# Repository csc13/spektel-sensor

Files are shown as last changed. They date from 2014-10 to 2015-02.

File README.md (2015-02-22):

spektel-sensor
==============
*[See the project blog here!](http://spektel.cescholz.de/)* 

This is a small project for a XMEGA based sensor for the Spektrum-RC telemetry system.
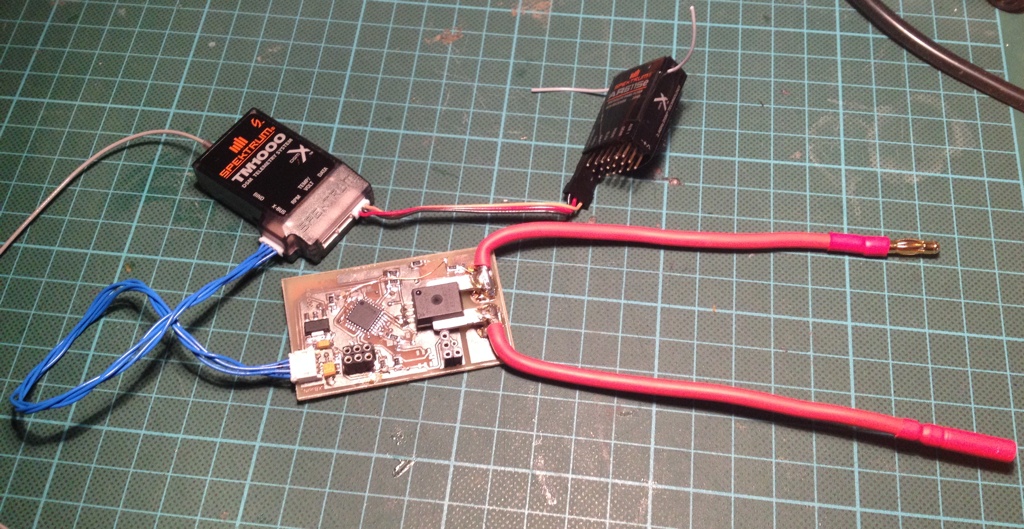
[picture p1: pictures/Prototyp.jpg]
spektrum Sensor Prototype


The sensor is based on the flowing components:
- Atmel XMEGA32E5
- Allegro ACS758LCB-100U hall effect current sensor
- Bosch BMP180 pressure sensor (planned)

The firmware was developed in C using Atmel Studio 6 and the Atmel ASF framework.

	Note: The Spektrum RC TM1000 telemetry modul, a DSMX receiver with data port and a 
	transmitter with telemetry functions are required to use the sensor. Not all Spektrum RC telemetry able
	transmitters support all sensors. I use a DX9 for testing.

### Basic functions
The sensor measures 25 times a second the actual current, voltage and pressure. From this 
it calculates the used capacity, hight and climb rate.

- Show used capacity of main battery
- Show actual current of main battery
- Show actual voltage of main battery
- Show altitude
- Programmable via on button (change the battery capacity)

### Planned functions
- Show climb rate
- Show cell voltages of main battery

### Project Structure
- firmware (compiled firmware for XMEGA)
- flight_logs (from Spektrum transmitter)
- hardware (Eagle PCB files)
- pictures (photos)
- project (Atmel Studio, make files, etc.)
- src (C sources)

### History
#### 2014-10-28: Initial upload with REV_A board layout
- Please note that REV_A is the initial prototype and has several bugs

#### 2014-11-02: Added support for RealtimePlotter and arduplot
Two two great serial monitors based on Processing (https://www.processing.org/).
Please see https://github.com/sebnil/RealtimePlotter.git and see https://github.com/dahart/arduplot.git).

#### 2015-01-19: Added support for the REV_B board
This includes the smaller board, BMP180 altitude measurement, setup button, self calibration.

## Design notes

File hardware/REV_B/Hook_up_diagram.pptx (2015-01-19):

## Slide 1

Spektrum TM1000

Optional GND connection, if not via receiver BEC from ESC

Main Battery pack

X-Bus

Spektel Sensor REV_B
(bottom side)

+

Electronic Speed Controller

spektel.cescholz.de

+

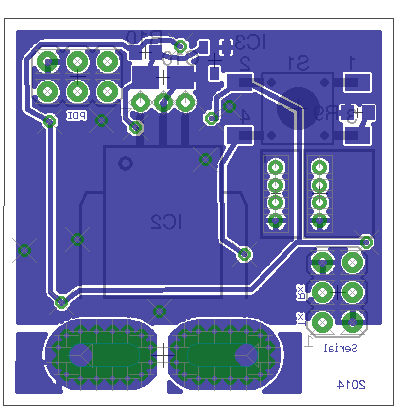
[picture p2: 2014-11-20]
hardware/REV_B/Bottom_Layer_REV_B.png

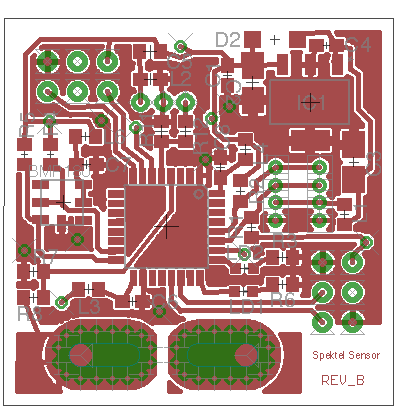
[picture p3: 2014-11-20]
hardware/REV_B/Top_Layer_REV_B.png

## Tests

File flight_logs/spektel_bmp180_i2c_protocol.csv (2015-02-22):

Time [s] | Analyzer Name | Decoded Protocol Result
0.000012825000000 | I2C | Setup Write to ['238' (0xEE)] + ACK
0.000053850000000 | I2C | '208' (0xD0) + ACK
0.000122950000000 | I2C | Setup Read to ['239' (0xEF)] + ACK
0.000161250000000 | I2C | U (0x55) + NAK
0.000234550000000 | I2C | Setup Write to ['238' (0xEE)] + ACK
0.000275575000000 | I2C | '244' (0xF4) + ACK
0.000317450000000 | I2C | '192' (0xC0) + ACK
0.000390350000000 | I2C | Setup Write to ['238' (0xEE)] + ACK
0.000431350000000 | I2C | '244' (0xF4) + ACK
0.000500450000000 | I2C | Setup Read to ['239' (0xEF)] + ACK
0.000538750000000 | I2C | '192' (0xC0) + NAK
0.000612050000000 | I2C | Setup Write to ['238' (0xEE)] + ACK
0.000653100000000 | I2C | '170' (0xAA) + ACK
0.000722225000000 | I2C | Setup Read to ['239' (0xEF)] + ACK
0.000760525000000 | I2C | ' ' (0x20) + ACK
0.000802175000000 | I2C | '212' (0xD4) + NAK
0.000875475000000 | I2C | Setup Write to ['238' (0xEE)] + ACK
0.000916525000000 | I2C | '172' (0xAC) + ACK
0.000985650000000 | I2C | Setup Read to ['239' (0xEF)] + ACK
0.001023950000000 | I2C | '251' (0xFB) + ACK
0.001065625000000 | I2C | r (0x72) + NAK
0.001139000000000 | I2C | Setup Write to ['238' (0xEE)] + ACK
0.001180025000000 | I2C | '174' (0xAE) + ACK
0.001249150000000 | I2C | Setup Read to ['239' (0xEF)] + ACK
0.001287425000000 | I2C | '199' (0xC7) + ACK
0.001329100000000 | I2C | # (0x23) + NAK
0.001402425000000 | I2C | Setup Write to ['238' (0xEE)] + ACK
0.001443450000000 | I2C | '176' (0xB0) + ACK
0.001512525000000 | I2C | Setup Read to ['239' (0xEF)] + ACK
0.001550825000000 | I2C | '128' (0x80) + ACK
0.001592500000000 | I2C | '234' (0xEA) + NAK
0.001665850000000 | I2C | Setup Write to ['238' (0xEE)] + ACK
0.001706875000000 | I2C | '178' (0xB2) + ACK
0.001776025000000 | I2C | Setup Read to ['239' (0xEF)] + ACK
0.001814325000000 | I2C | b (0x62) + ACK
0.001855950000000 | I2C | '203' (0xCB) + NAK
0.001929300000000 | I2C | Setup Write to ['238' (0xEE)] + ACK
0.001970325000000 | I2C | '180' (0xB4) + ACK
0.002039425000000 | I2C | Setup Read to ['239' (0xEF)] + ACK
0.002077725000000 | I2C | E (0x45) + ACK
0.002119400000000 | I2C | 1 (0x31) + NAK
0.002192750000000 | I2C | Setup Write to ['238' (0xEE)] + ACK
0.002233800000000 | I2C | '182' (0xB6) + ACK
0.002302925000000 | I2C | Setup Read to ['239' (0xEF)] + ACK
0.002341225000000 | I2C | '25' (0x19) + ACK
0.002382900000000 | I2C | s (0x73) + NAK
0.002456275000000 | I2C | Setup Write to ['238' (0xEE)] + ACK
0.002497275000000 | I2C | '184' (0xB8) + ACK
0.002566375000000 | I2C | Setup Read to ['239' (0xEF)] + ACK
0.002604700000000 | I2C | '0' (0x00) + ACK
0.002646375000000 | I2C | - (0x2D) + NAK
0.002719750000000 | I2C | Setup Write to ['238' (0xEE)] + ACK
0.002760775000000 | I2C | '186' (0xBA) + ACK
0.002829900000000 | I2C | Setup Read to ['239' (0xEF)] + ACK
0.002868200000000 | I2C | '128' (0x80) + ACK
0.002909875000000 | I2C | '0' (0x00) + NAK
0.002983250000000 | I2C | Setup Write to ['238' (0xEE)] + ACK
0.003024275000000 | I2C | '188' (0xBC) + ACK
0.003093375000000 | I2C | Setup Read to ['239' (0xEF)] + ACK
0.003131700000000 | I2C | '209' (0xD1) + ACK
0.003173375000000 | I2C | '246' (0xF6) + NAK
0.003246750000000 | I2C | Setup Write to ['238' (0xEE)] + ACK
0.003287775000000 | I2C | '190' (0xBE) + ACK
0.003356900000000 | I2C | Setup Read to ['239' (0xEF)] + ACK
0.003395225000000 | I2C | \n (0x0A) + ACK
0.003436900000000 | I2C | S (0x53) + NAK
0.003510275000000 | I2C | Setup Write to ['238' (0xEE)] + ACK
0.003551350000000 | I2C | '244' (0xF4) + ACK
0.003593250000000 | I2C | . (0x2E) + ACK
0.008666775000000 | I2C | Setup Write to ['238' (0xEE)] + ACK
0.008707800000000 | I2C | '246' (0xF6) + ACK
0.008776900000000 | I2C | Setup Read to ['239' (0xEF)] + ACK
0.008815200000000 | I2C | c (0x63) + ACK
0.008856850000000 | I2C | '225' (0xE1) + NAK
0.009004475000000 | I2C | Setup Write to ['238' (0xEE)] + ACK
0.009045475000000 | I2C | '244' (0xF4) + ACK
0.009087375000000 | I2C | '244' (0xF4) + ACK
0.020256700000000 | I2C | Setup Write to ['238' (0xEE)] + ACK
0.020297725000000 | I2C | '246' (0xF6) + ACK
0.020366875000000 | I2C | Setup Read to ['239' (0xEF)] + ACK
0.020405200000000 | I2C | c (0x63) + ACK
0.020446850000000 | I2C | '225' (0xE1) + NAK
0.020520200000000 | I2C | Setup Write to ['238' (0xEE)] + ACK
0.020561250000000 | I2C | '248' (0xF8) + ACK
0.020630375000000 | I2C | Setup Read to ['239' (0xEF)] + ACK
0.020668675000000 | I2C | '0' (0x00) + NAK
0.021004075000000 | I2C | Setup Write to ['238' (0xEE)] + ACK
0.021045150000000 | I2C | '244' (0xF4) + ACK
0.021087050000000 | I2C | '244' (0xF4) + ACK
0.060308250000000 | I2C | Setup Write to ['238' (0xEE)] + ACK
0.060349275000000 | I2C | '246' (0xF6) + ACK
0.060418350000000 | I2C | Setup Read to ['239' (0xEF)] + ACK
0.060456625000000 | I2C | '162' (0xA2) + ACK
0.060498275000000 | I2C | '216' (0xD8) + NAK
0.060571625000000 | I2C | Setup Write to ['238' (0xEE)] + ACK
0.060612625000000 | I2C | '248' (0xF8) + ACK
0.060681725000000 | I2C | Setup Read to ['239' (0xEF)] + ACK
0.060720025000000 | I2C | '128' (0x80) + NAK
0.061027975000000 | I2C | Setup Write to ['238' (0xEE)] + ACK
0.061069050000000 | I2C | '244' (0xF4) + ACK
0.061110950000000 | I2C | '244' (0xF4) + ACK
0.100361000000000 | I2C | Setup Write to ['238' (0xEE)] + ACK
0.100402000000000 | I2C | '246' (0xF6) + ACK
0.100471125000000 | I2C | Setup Read to ['239' (0xEF)] + ACK
0.100509425000000 | I2C | '162' (0xA2) + ACK
0.100551100000000 | I2C | '215' (0xD7) + NAK
0.100624400000000 | I2C | Setup Write to ['238' (0xEE)] + ACK
0.100665400000000 | I2C | '248' (0xF8) + ACK
0.100734500000000 | I2C | Setup Read to ['239' (0xEF)] + ACK
0.100772775000000 | I2C | @ (0x40) + NAK
0.101084575000000 | I2C | Setup Write to ['238' (0xEE)] + ACK
0.101125625000000 | I2C | '244' (0xF4) + ACK
0.101167450000000 | I2C | '244' (0xF4) + ACK
0.140422050000000 | I2C | Setup Write to ['238' (0xEE)] + ACK
0.140463075000000 | I2C | '246' (0xF6) + ACK
0.140532225000000 | I2C | Setup Read to ['239' (0xEF)] + ACK
0.140570525000000 | I2C | '162' (0xA2) + ACK
0.140612225000000 | I2C | '216' (0xD8) + NAK
0.140685600000000 | I2C | Setup Write to ['238' (0xEE)] + ACK
0.140726650000000 | I2C | '248' (0xF8) + ACK
0.140795825000000 | I2C | Setup Read to ['239' (0xEF)] + ACK
0.140834125000000 | I2C | ` (0x60) + NAK
0.141142250000000 | I2C | Setup Write to ['238' (0xEE)] + ACK
0.141183300000000 | I2C | '244' (0xF4) + ACK
0.141225200000000 | I2C | '244' (0xF4) + ACK
0.180482600000000 | I2C | Setup Write to ['238' (0xEE)] + ACK
0.180523650000000 | I2C | '246' (0xF6) + ACK
0.180592800000000 | I2C | Setup Read to ['239' (0xEF)] + ACK
0.180631100000000 | I2C | '162' (0xA2) + ACK
0.180672800000000 | I2C | '215' (0xD7) + NAK
0.180746200000000 | I2C | Setup Write to ['238' (0xEE)] + ACK
0.180787250000000 | I2C | '248' (0xF8) + ACK
0.180856400000000 | I2C | Setup Read to ['239' (0xEF)] + ACK
0.180894725000000 | I2C | '192' (0xC0) + NAK
0.181214550000000 | I2C | Setup Write to ['238' (0xEE)] + ACK
0.181255600000000 | I2C | '244' (0xF4) + ACK
0.181297450000000 | I2C | '244' (0xF4) + ACK
0.220544125000000 | I2C | Setup Write to ['238' (0xEE)] + ACK
0.220585200000000 | I2C | '246' (0xF6) + ACK
0.220654325000000 | I2C | Setup Read to ['239' (0xEF)] + ACK
0.220692625000000 | I2C | '162' (0xA2) + ACK
0.220734300000000 | I2C | '214' (0xD6) + NAK
0.220807675000000 | I2C | Setup Write to ['238' (0xEE)] + ACK
0.220848700000000 | I2C | '248' (0xF8) + ACK
0.220917850000000 | I2C | Setup Read to ['239' (0xEF)] + ACK
0.220956150000000 | I2C | '160' (0xA0) + NAK
0.221268125000000 | I2C | Setup Write to ['238' (0xEE)] + ACK
0.221309150000000 | I2C | '244' (0xF4) + ACK
0.221351050000000 | I2C | '244' (0xF4) + ACK
0.225667600000000 | I2C | Setup Read to ['255' (0xFF)] + NAK
0.240098025000000 | I2C | Setup Write to ['238' (0xEE)] + ACK
0.240139050000000 | I2C | '208' (0xD0) + ACK
0.240208200000000 | I2C | Setup Read to ['239' (0xEF)] + ACK
0.240246500000000 | I2C | U (0x55) + NAK
0.240319875000000 | I2C | Setup Write to ['238' (0xEE)] + ACK
0.240360925000000 | I2C | '244' (0xF4) + ACK
0.240402825000000 | I2C | '192' (0xC0) + ACK
0.240475800000000 | I2C | Setup Write to ['238' (0xEE)] + ACK
0.240516850000000 | I2C | '244' (0xF4) + ACK
0.240586000000000 | I2C | Setup Read to ['239' (0xEF)] + ACK
0.240624350000000 | I2C | '192' (0xC0) + NAK
0.240697750000000 | I2C | Setup Write to ['238' (0xEE)] + ACK
0.240738850000000 | I2C | '170' (0xAA) + ACK
0.240808050000000 | I2C | Setup Read to ['239' (0xEF)] + ACK
0.240846375000000 | I2C | ' ' (0x20) + ACK
0.240888075000000 | I2C | '212' (0xD4) + NAK
0.240961475000000 | I2C | Setup Write to ['238' (0xEE)] + ACK
0.241002600000000 | I2C | '172' (0xAC) + ACK
0.241071800000000 | I2C | Setup Read to ['239' (0xEF)] + ACK
0.241110125000000 | I2C | '251' (0xFB) + ACK
0.241151825000000 | I2C | r (0x72) + NAK
0.241225225000000 | I2C | Setup Write to ['238' (0xEE)] + ACK
0.241266250000000 | I2C | '174' (0xAE) + ACK
0.241335400000000 | I2C | Setup Read to ['239' (0xEF)] + ACK
0.241373750000000 | I2C | '199' (0xC7) + ACK
0.241415450000000 | I2C | # (0x23) + NAK
0.241488825000000 | I2C | Setup Write to ['238' (0xEE)] + ACK
0.241529875000000 | I2C | '176' (0xB0) + ACK
0.241599000000000 | I2C | Setup Read to ['239' (0xEF)] + ACK
0.241637325000000 | I2C | '128' (0x80) + ACK
0.241679025000000 | I2C | '234' (0xEA) + NAK
0.241752450000000 | I2C | Setup Write to ['238' (0xEE)] + ACK
0.241793525000000 | I2C | '178' (0xB2) + ACK
0.241862700000000 | I2C | Setup Read to ['239' (0xEF)] + ACK
0.241901025000000 | I2C | b (0x62) + ACK
0.241942750000000 | I2C | '203' (0xCB) + NAK
0.242016175000000 | I2C | Setup Write to ['238' (0xEE)] + ACK
0.242057225000000 | I2C | '180' (0xB4) + ACK
0.242126450000000 | I2C | Setup Read to ['239' (0xEF)] + ACK
0.242164800000000 | I2C | E (0x45) + ACK
0.242206500000000 | I2C | 1 (0x31) + NAK
0.242279900000000 | I2C | Setup Write to ['238' (0xEE)] + ACK
0.242320975000000 | I2C | '182' (0xB6) + ACK
0.242390150000000 | I2C | Setup Read to ['239' (0xEF)] + ACK
0.242428475000000 | I2C | '25' (0x19) + ACK
0.242470175000000 | I2C | s (0x73) + NAK
0.242543575000000 | I2C | Setup Write to ['238' (0xEE)] + ACK
0.242584625000000 | I2C | '184' (0xB8) + ACK
0.242653800000000 | I2C | Setup Read to ['239' (0xEF)] + ACK
0.242692125000000 | I2C | '0' (0x00) + ACK
0.242733825000000 | I2C | - (0x2D) + NAK
0.242807250000000 | I2C | Setup Write to ['238' (0xEE)] + ACK
0.242848300000000 | I2C | '186' (0xBA) + ACK
0.242917450000000 | I2C | Setup Read to ['239' (0xEF)] + ACK
0.242955775000000 | I2C | '128' (0x80) + ACK
0.242997475000000 | I2C | '0' (0x00) + NAK
0.243070900000000 | I2C | Setup Write to ['238' (0xEE)] + ACK
0.243111950000000 | I2C | '188' (0xBC) + ACK
0.243181100000000 | I2C | Setup Read to ['239' (0xEF)] + ACK
0.243219450000000 | I2C | '209' (0xD1) + ACK
0.243261125000000 | I2C | '246' (0xF6) + NAK
0.243334550000000 | I2C | Setup Write to ['238' (0xEE)] + ACK
0.243375600000000 | I2C | '190' (0xBE) + ACK
0.243444775000000 | I2C | Setup Read to ['239' (0xEF)] + ACK
0.243483100000000 | I2C | \n (0x0A) + ACK
0.243524800000000 | I2C | S (0x53) + NAK
0.243598225000000 | I2C | Setup Write to ['238' (0xEE)] + ACK
0.243639300000000 | I2C | '244' (0xF4) + ACK
0.243681225000000 | I2C | . (0x2E) + ACK
0.248758475000000 | I2C | Setup Write to ['238' (0xEE)] + ACK
0.248799575000000 | I2C | '246' (0xF6) + ACK
0.248868775000000 | I2C | Setup Read to ['239' (0xEF)] + ACK
0.248907100000000 | I2C | c (0x63) + ACK
0.248948800000000 | I2C | '231' (0xE7) + NAK
0.249096600000000 | I2C | Setup Write to ['238' (0xEE)] + ACK
0.249137675000000 | I2C | '244' (0xF4) + ACK
0.249179600000000 | I2C | '244' (0xF4) + ACK
0.260358300000000 | I2C | Setup Write to ['238' (0xEE)] + ACK
0.260399350000000 | I2C | '246' (0xF6) + ACK
0.260468550000000 | I2C | Setup Read to ['239' (0xEF)] + ACK
0.260506875000000 | I2C | c (0x63) + ACK
0.260548575000000 | I2C | '231' (0xE7) + NAK
0.260622000000000 | I2C | Setup Write to ['238' (0xEE)] + ACK
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

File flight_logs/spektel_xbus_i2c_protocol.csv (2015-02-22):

Time [s] | Packet ID | Address | Data | Read/Write | ACK/NAK
0.073835750000000 | 0 | 0x03 | 0x00 | Read | ACK
0.073953575000000 | 0 | 0x03 | 0x00 | Read | ACK
0.074063475000000 | 0 | 0x03 | 0x00 | Read | ACK
0.074173350000000 | 0 | 0x03 | 0x00 | Read | ACK
0.074283250000000 | 0 | 0x03 | 0x00 | Read | ACK
0.074393125000000 | 0 | 0x03 | 0x00 | Read | ACK
0.074504325000000 | 0 | 0x03 | 0x00 | Read | ACK
0.074614200000000 | 0 | 0x03 | 0x00 | Read | ACK
0.074724075000000 | 0 | 0x03 | 0x00 | Read | ACK
0.074833975000000 | 0 | 0x03 | 0x00 | Read | ACK
0.074943850000000 | 0 | 0x03 | 0x00 | Read | ACK
0.075055725000000 | 0 | 0x03 | 0x00 | Read | ACK
0.075165600000000 | 0 | 0x03 | 0x00 | Read | ACK
0.075275475000000 | 0 | 0x03 | 0x00 | Read | ACK
0.075385375000000 | 0 | 0x03 | 0x00 | Read | ACK
0.075495250000000 | 0 | 0x03 | 0x00 | Read | NAK
0.087534100000000 | 1 | 0x03 | 0x0A | Read | ACK
0.087643975000000 | 1 | 0x03 | 0x00 | Read | ACK
0.087753850000000 | 1 | 0x03 | 0x00 | Read | ACK
0.087863750000000 | 1 | 0x03 | 0x00 | Read | ACK
0.087984875000000 | 1 | 0x03 | 0x01 | Read | ACK
0.088094750000000 | 1 | 0x03 | 0xD7 | Read | ACK
0.088204650000000 | 1 | 0x03 | 0x0C | Read | ACK
0.088314525000000 | 1 | 0x03 | 0xE4 | Read | ACK
0.088424425000000 | 1 | 0x03 | 0x00 | Read | ACK
0.088536300000000 | 1 | 0x03 | 0x00 | Read | ACK
0.088646175000000 | 1 | 0x03 | 0x00 | Read | ACK
0.088756050000000 | 1 | 0x03 | 0x00 | Read | ACK
0.088865950000000 | 1 | 0x03 | 0x00 | Read | ACK
0.088975825000000 | 1 | 0x03 | 0x00 | Read | ACK
0.089086375000000 | 1 | 0x03 | 0x00 | Read | ACK
0.089196250000000 | 1 | 0x03 | 0x00 | Read | NAK
0.101225950000000 | 2 | 0x05 | 0x03 | Read | ACK
0.101335825000000 | 2 | 0x05 | 0x00 | Read | ACK
0.101445725000000 | 2 | 0x05 | 0x00 | Read | ACK
0.101555600000000 | 2 | 0x05 | 0x00 | Read | ACK
0.101665500000000 | 2 | 0x05 | 0x00 | Read | ACK
0.101775375000000 | 2 | 0x05 | 0x00 | Read | ACK
0.101885925000000 | 2 | 0x05 | 0x00 | Read | ACK
0.101995800000000 | 2 | 0x05 | 0x00 | Read | ACK
0.102105700000000 | 2 | 0x05 | 0x00 | Read | ACK
0.102215575000000 | 2 | 0x05 | 0x00 | Read | ACK
0.102325475000000 | 2 | 0x05 | 0x00 | Read | ACK
0.102436675000000 | 2 | 0x05 | 0x00 | Read | ACK
0.102546575000000 | 2 | 0x05 | 0x00 | Read | ACK
0.102656450000000 | 2 | 0x05 | 0x00 | Read | ACK
0.102766350000000 | 2 | 0x05 | 0x00 | Read | ACK
0.102876225000000 | 2 | 0x05 | 0x00 | Read | NAK
0.114706575000000 | 3 | 0x05 | 0x40 | Read | ACK
0.114816475000000 | 3 | 0x05 | 0x00 | Read | ACK
0.114926350000000 | 3 | 0x05 | 0xA1 | Read | ACK
0.115036225000000 | 3 | 0x05 | 0x37 | Read | ACK
0.115146125000000 | 3 | 0x05 | 0x00 | Read | ACK
0.115259975000000 | 3 | 0x05 | 0x00 | Read | ACK
0.115369850000000 | 3 | 0x05 | 0x00 | Read | ACK
0.115479725000000 | 3 | 0x05 | 0x00 | Read | ACK
0.115589625000000 | 3 | 0x05 | 0x00 | Read | ACK
0.115699500000000 | 3 | 0x05 | 0x00 | Read | ACK
0.115810025000000 | 3 | 0x05 | 0x00 | Read | ACK
0.115919900000000 | 3 | 0x05 | 0x00 | Read | ACK
0.116029775000000 | 3 | 0x05 | 0x00 | Read | ACK
0.116139675000000 | 3 | 0x05 | 0x00 | Read | ACK
0.116249525000000 | 3 | 0x05 | 0x00 | Read | ACK
0.116361400000000 | 3 | 0x05 | 0x00 | Read | NAK
0.128412800000000 | 4 | 0x07 | 0x0A | Read | ACK
0.128522675000000 | 4 | 0x07 | 0x00 | Read | ACK
0.128632550000000 | 4 | 0x07 | 0x00 | Read | ACK
0.128742450000000 | 4 | 0x07 | 0x00 | Read | ACK
0.128852325000000 | 4 | 0x07 | 0x01 | Read | ACK
0.128962200000000 | 4 | 0x07 | 0xD8 | Read | ACK
0.129072100000000 | 4 | 0x07 | 0x0C | Read | ACK
0.129182625000000 | 4 | 0x07 | 0xE4 | Read | ACK
0.129292525000000 | 4 | 0x07 | 0x00 | Read | ACK
0.129402400000000 | 4 | 0x07 | 0x00 | Read | ACK
0.129512275000000 | 4 | 0x07 | 0x00 | Read | ACK
0.129622175000000 | 4 | 0x07 | 0x00 | Read | ACK
0.129732050000000 | 4 | 0x07 | 0x00 | Read | ACK
0.129841925000000 | 4 | 0x07 | 0x00 | Read | ACK
0.129951825000000 | 4 | 0x07 | 0x00 | Read | ACK
0.130061700000000 | 4 | 0x07 | 0x00 | Read | NAK
0.141905000000000 | 5 | 0x07 | 0x03 | Read | ACK
0.142015550000000 | 5 | 0x07 | 0x00 | Read | ACK
0.142125425000000 | 5 | 0x07 | 0x00 | Read | ACK
0.142245250000000 | 5 | 0x07 | 0x00 | Read | ACK
0.142355125000000 | 5 | 0x07 | 0x00 | Read | ACK
0.142465000000000 | 5 | 0x07 | 0x00 | Read | ACK
0.142574875000000 | 5 | 0x07 | 0x00 | Read | ACK
0.142684750000000 | 5 | 0x07 | 0x00 | Read | ACK
0.142796625000000 | 5 | 0x07 | 0x00 | Read | ACK
0.142906500000000 | 5 | 0x07 | 0x00 | Read | ACK
0.143016375000000 | 5 | 0x07 | 0x00 | Read | ACK
0.143126275000000 | 5 | 0x07 | 0x00 | Read | ACK
0.143236150000000 | 5 | 0x07 | 0x00 | Read | ACK
0.143347350000000 | 5 | 0x07 | 0x00 | Read | ACK
0.143457225000000 | 5 | 0x07 | 0x00 | Read | ACK
0.143567100000000 | 5 | 0x07 | 0x00 | Read | NAK
0.155498950000000 |  | 0x09 |  | Read | NAK
0.168541125000000 |  | 0x09 |  | Read | NAK
0.181801075000000 |  | 0x0B |  | Read | NAK
0.194861325000000 |  | 0x0B |  | Read | NAK
0.208125350000000 |  | 0x0D |  | Read | NAK
0.221178775000000 |  | 0x0D |  | Read | NAK
0.234443500000000 |  | 0x0F |  | Read | NAK
0.247502050000000 |  | 0x0F |  | Read | NAK
0.260880600000000 | 14 | 0x11 | 0x40 | Read | ACK
0.260991150000000 | 14 | 0x11 | 0x00 | Read | ACK
0.261101025000000 | 14 | 0x11 | 0x5E | Read | ACK
0.261210925000000 | 14 | 0x11 | 0xCF | Read | ACK
0.261322775000000 | 14 | 0x11 | 0x00 | Read | ACK
0.261432675000000 | 14 | 0x11 | 0x00 | Read | ACK
0.261542550000000 | 14 | 0x11 | 0x00 | Read | ACK
0.261652425000000 | 14 | 0x11 | 0x00 | Read | ACK
0.261762300000000 | 14 | 0x11 | 0x00 | Read | ACK
0.261873525000000 | 14 | 0x11 | 0x00 | Read | ACK
0.261983400000000 | 14 | 0x11 | 0x00 | Read | ACK
0.262093275000000 | 14 | 0x11 | 0x00 | Read | ACK
0.262203175000000 | 14 | 0x11 | 0x00 | Read | ACK
0.262313050000000 | 14 | 0x11 | 0x00 | Read | ACK
0.262424250000000 | 14 | 0x11 | 0x00 | Read | ACK
0.262534150000000 | 14 | 0x11 | 0x00 | Read | NAK
0.274360550000000 | 15 | 0x11 | 0x0A | Read | ACK
0.274470425000000 | 15 | 0x11 | 0x00 | Read | ACK
0.274580300000000 | 15 | 0x11 | 0x00 | Read | ACK
0.274690175000000 | 15 | 0x11 | 0x00 | Read | ACK
0.274800050000000 | 15 | 0x11 | 0x01 | Read | ACK
0.274909950000000 | 15 | 0x11 | 0xE8 | Read | ACK
0.275019825000000 | 15 | 0x11 | 0x0C | Read | ACK
0.275129700000000 | 15 | 0x11 | 0xE4 | Read | ACK
0.275239575000000 | 15 | 0x11 | 0x00 | Read | ACK
0.275349450000000 | 15 | 0x11 | 0x00 | Read | ACK
0.275459325000000 | 15 | 0x11 | 0x00 | Read | ACK
0.275569225000000 | 15 | 0x11 | 0x00 | Read | ACK
0.275679100000000 | 15 | 0x11 | 0x00 | Read | ACK
0.275788975000000 | 15 | 0x11 | 0x00 | Read | ACK
0.275898850000000 | 15 | 0x11 | 0x00 | Read | ACK
0.276009400000000 | 15 | 0x11 | 0x00 | Read | NAK
0.288067025000000 | 16 | 0x13 | 0x03 | Read | ACK
0.288189475000000 | 16 | 0x13 | 0x00 | Read | ACK
0.288299350000000 | 16 | 0x13 | 0x00 | Read | ACK
0.288409225000000 | 16 | 0x13 | 0x00 | Read | ACK
0.288519100000000 | 16 | 0x13 | 0x00 | Read | ACK
0.288628975000000 | 16 | 0x13 | 0x00 | Read | ACK
0.288740175000000 | 16 | 0x13 | 0x00 | Read | ACK
0.288850075000000 | 16 | 0x13 | 0x00 | Read | ACK
0.288959950000000 | 16 | 0x13 | 0x00 | Read | ACK
0.289069825000000 | 16 | 0x13 | 0x00 | Read | ACK
0.289179700000000 | 16 | 0x13 | 0x00 | Read | ACK
0.289290925000000 | 16 | 0x13 | 0x00 | Read | ACK
0.289400800000000 | 16 | 0x13 | 0x00 | Read | ACK
0.289510675000000 | 16 | 0x13 | 0x00 | Read | ACK
0.289620550000000 | 16 | 0x13 | 0x00 | Read | ACK
0.289730425000000 | 16 | 0x13 | 0x00 | Read | NAK
0.301560575000000 | 17 | 0x13 | 0x40 | Read | ACK
0.301670475000000 | 17 | 0x13 | 0x00 | Read | ACK
0.301780350000000 | 17 | 0x13 | 0xDD | Read | ACK
0.301890225000000 | 17 | 0x13 | 0x9B | Read | ACK
0.302000100000000 | 17 | 0x13 | 0x00 | Read | ACK
0.302110000000000 | 17 | 0x13 | 0x00 | Read | ACK
0.302219875000000 | 17 | 0x13 | 0x00 | Read | ACK
0.302329750000000 | 17 | 0x13 | 0x00 | Read | ACK
0.302439625000000 | 17 | 0x13 | 0x00 | Read | ACK
0.302549525000000 | 17 | 0x13 | 0x00 | Read | ACK
0.302659400000000 | 17 | 0x13 | 0x00 | Read | ACK
0.302771250000000 | 17 | 0x13 | 0x00 | Read | ACK
0.302881150000000 | 17 | 0x13 | 0x00 | Read | ACK
0.302991025000000 | 17 | 0x13 | 0x00 | Read | ACK
0.303100900000000 | 17 | 0x13 | 0x00 | Read | ACK
0.303210800000000 | 17 | 0x13 | 0x00 | Read | NAK
0.315267000000000 | 18 | 0x15 | 0x0A | Read | ACK
0.315376875000000 | 18 | 0x15 | 0x00 | Read | ACK
0.315486750000000 | 18 | 0x15 | 0x00 | Read | ACK
0.315596650000000 | 18 | 0x15 | 0x00 | Read | ACK
0.315725725000000 | 18 | 0x15 | 0x01 | Read | ACK
0.315835600000000 | 18 | 0x15 | 0xF0 | Read | ACK
0.315945475000000 | 18 | 0x15 | 0x0C | Read | ACK
0.316055350000000 | 18 | 0x15 | 0xE4 | Read | ACK
0.316165225000000 | 18 | 0x15 | 0x00 | Read | ACK
0.316276425000000 | 18 | 0x15 | 0x00 | Read | ACK
0.316386975000000 | 18 | 0x15 | 0x00 | Read | ACK
0.316496825000000 | 18 | 0x15 | 0x00 | Read | ACK
0.316607375000000 | 18 | 0x15 | 0x00 | Read | ACK
0.316717250000000 | 18 | 0x15 | 0x00 | Read | ACK
0.316827125000000 | 18 | 0x15 | 0x00 | Read | ACK
0.316937000000000 | 18 | 0x15 | 0x00 | Read | NAK
0.328746875000000 | 19 | 0x15 | 0x03 | Read | ACK
0.328856750000000 | 19 | 0x15 | 0x00 | Read | ACK
0.328966650000000 | 19 | 0x15 | 0x00 | Read | ACK
0.329076525000000 | 19 | 0x15 | 0x00 | Read | ACK
0.329186400000000 | 19 | 0x15 | 0x00 | Read | ACK
0.329296300000000 | 19 | 0x15 | 0x00 | Read | ACK
0.329406175000000 | 19 | 0x15 | 0x00 | Read | ACK
0.329516050000000 | 19 | 0x15 | 0x00 | Read | ACK
0.329625925000000 | 19 | 0x15 | 0x00 | Read | ACK
0.329735825000000 | 19 | 0x15 | 0x00 | Read | ACK
0.329845700000000 | 19 | 0x15 | 0x00 | Read | ACK
0.329955575000000 | 19 | 0x15 | 0x00 | Read | ACK
0.330065475000000 | 19 | 0x15 | 0x00 | Read | ACK
0.330176000000000 | 19 | 0x15 | 0x00 | Read | ACK
0.330285900000000 | 19 | 0x15 | 0x00 | Read | ACK
0.330395775000000 | 19 | 0x15 | 0x00 | Read | NAK
0.342440175000000 | 20 | 0x17 | 0x40 | Read | ACK
0.342554700000000 | 20 | 0x17 | 0x00 | Read | ACK
0.342664575000000 | 20 | 0x17 | 0xBE | Read | ACK
0.342774450000000 | 20 | 0x17 | 0xC8 | Read | ACK
0.342884350000000 | 20 | 0x17 | 0x00 | Read | ACK
0.342994225000000 | 20 | 0x17 | 0x00 | Read | ACK
0.343105425000000 | 20 | 0x17 | 0x00 | Read | ACK
0.343215325000000 | 20 | 0x17 | 0x00 | Read | ACK
0.343325200000000 | 20 | 0x17 | 0x00 | Read | ACK
0.343435075000000 | 20 | 0x17 | 0x00 | Read | ACK
0.343544975000000 | 20 | 0x17 | 0x00 | Read | ACK
0.343656175000000 | 20 | 0x17 | 0x00 | Read | ACK
0.343766075000000 | 20 | 0x17 | 0x00 | Read | ACK
0.343875950000000 | 20 | 0x17 | 0x00 | Read | ACK
0.343985825000000 | 20 | 0x17 | 0x00 | Read | ACK
0.344095725000000 | 20 | 0x17 | 0x00 | Read | NAK
0.355918625000000 | 21 | 0x17 | 0x0A | Read | ACK
0.356028500000000 | 21 | 0x17 | 0x00 | Read | ACK
0.356138375000000 | 21 | 0x17 | 0x00 | Read | ACK
0.356248250000000 | 21 | 0x17 | 0x00 | Read | ACK
0.356358125000000 | 21 | 0x17 | 0x01 | Read | ACK
0.356479250000000 | 21 | 0x17 | 0xFA | Read | ACK
0.356589125000000 | 21 | 0x17 | 0x0C | Read | ACK
0.356699000000000 | 21 | 0x17 | 0xE4 | Read | ACK
0.356808875000000 | 21 | 0x17 | 0x00 | Read | ACK
0.356918750000000 | 21 | 0x17 | 0x00 | Read | ACK
0.357029950000000 | 21 | 0x17 | 0x00 | Read | ACK
0.357139825000000 | 21 | 0x17 | 0x00 | Read | ACK
0.357249700000000 | 21 | 0x17 | 0x00 | Read | ACK
0.357359600000000 | 21 | 0x17 | 0x00 | Read | ACK
0.357469450000000 | 21 | 0x17 | 0x00 | Read | ACK
0.357580675000000 | 21 | 0x17 | 0x00 | Read | NAK
0.369531275000000 |  | 0x19 |  | Read | NAK
0.382576300000000 |  | 0x19 |  | Read | NAK
0.395853075000000 |  | 0x1B |  | Read | NAK
0.408907175000000 |  | 0x1B |  | Read | NAK
0.422172950000000 |  | 0x1D |  | Read | NAK
0.435233425000000 |  | 0x1D |  | Read | NAK
0.448499550000000 |  | 0x1F |  | Read | NAK
0.461541350000000 |  | 0x1F |  | Read | NAK
0.474810050000000 |  | 0x21 |  | Read | NAK
0.487869450000000 |  | 0x21 |  | Read | NAK
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

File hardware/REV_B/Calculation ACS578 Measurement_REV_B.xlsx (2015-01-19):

max bei 16 bit | 65536
RESOLUTION | 12 |  |  | Sample Calculation:
ADC_USIG_BASE | 162 |  |  | RES: | 727
CUR_RES_DIV | 1.683589744 |  |  |  | 303.048067
ADC_MV_12RES | 0.4899
ACS758_BASE | 400
ACS758_RATE | 26.4
ACS758_RATE_M1 | 0.264
ACS758_RATE_M | 0.0264
ACS_B | 475
ADC_B | 630
ACS_R | 0.03124206876
ACS_R_M1 | 3.124206876
ACS_R_M | 31.24206876
ADC_B | 562
 |  | ACS_R_O | ACS_R_M1_O | ACS_R_M_O | 4096
1 | 2 | 0.06248413753 | 6.248413753 | 62.48413753 | 255.9350273 | 25593.50273 | 255935.0273
2 | 4 | 0.1249682751 | 12.49682751 | 124.9682751 | 511.8700546 | 51187.00546 | 511870.0546
3 | 8 | 0.2499365501 | 24.99365501 | 249.9365501 | 1023.740109 | 102374.0109 | 1023740.109
4 | 16 | 0.4998731002 | 49.98731002 | 499.8731002 | 2047.480219 | 204748.0219 | 2047480.219
5 | 32 | 0.9997462005 | 99.97462005 | 999.7462005 | 4094.960437 | 409496.0437 | 4094960.437
6 | 64 | 1.999492401 | 199.9492401 | 1999.492401 | 8189.920874 | 818992.0874 | 8189920.874
7 | 128 | 3.998984802 | 399.8984802 | 3998.984802 | 16379.84175 | 1637984.175 | 16379841.75
8 | 265 | 8.279148223 | 827.9148223 | 8279.148223 | 33911.39112 | 3391139.112 | 33911391.12
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

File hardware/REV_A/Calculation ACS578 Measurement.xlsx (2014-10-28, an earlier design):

max bei 16 bit | 65536
RESOLUTION | 12
ADC_USIG_BASE | 162
ADC_MV_12RES | 0.4899
ACS758_BASE | 400
ACS758_RATE | 26.4
ACS758_RATE_M1 | 0.264
ACS758_RATE_M | 0.0264
ACS_B | 816
ADC_B | 978
ACS_R | 0.01855681818
ACS_R_M1 | 1.855681818
ACS_R_M | 18.55681818
ADC_B | 562
 |  | ACS_R_O | ACS_R_M1_O | ACS_R_M_O | 4096
1 | 2 | 0.03711363636 | 3.711363636 | 37.11363636 | 152.0174545 | 15201.74545 | 152017.4545
2 | 4 | 0.07422727273 | 7.422727273 | 74.22727273 | 304.0349091 | 30403.49091 | 304034.9091
3 | 8 | 0.1484545455 | 14.84545455 | 148.4545455 | 608.0698182 | 60806.98182 | 608069.8182
4 | 16 | 0.2969090909 | 29.69090909 | 296.9090909 | 1216.139636 | 121613.9636 | 1216139.636
5 | 32 | 0.5938181818 | 59.38181818 | 593.8181818 | 2432.279273 | 243227.9273 | 2432279.273
6 | 64 | 1.187636364 | 118.7636364 | 1187.636364 | 4864.558545 | 486455.8545 | 4864558.545
7 | 128 | 2.375272727 | 237.5272727 | 2375.272727 | 9729.117091 | 972911.7091 | 9729117.091
8 | 265 | 4.917556818 | 491.7556818 | 4917.556818 | 20142.31273 | 2014231.273 | 20142312.73
9 | 512 | 9.501090909 | 950.1090909 | 9501.090909 | 38916.46836 | 3891646.836 | 38916468.36
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

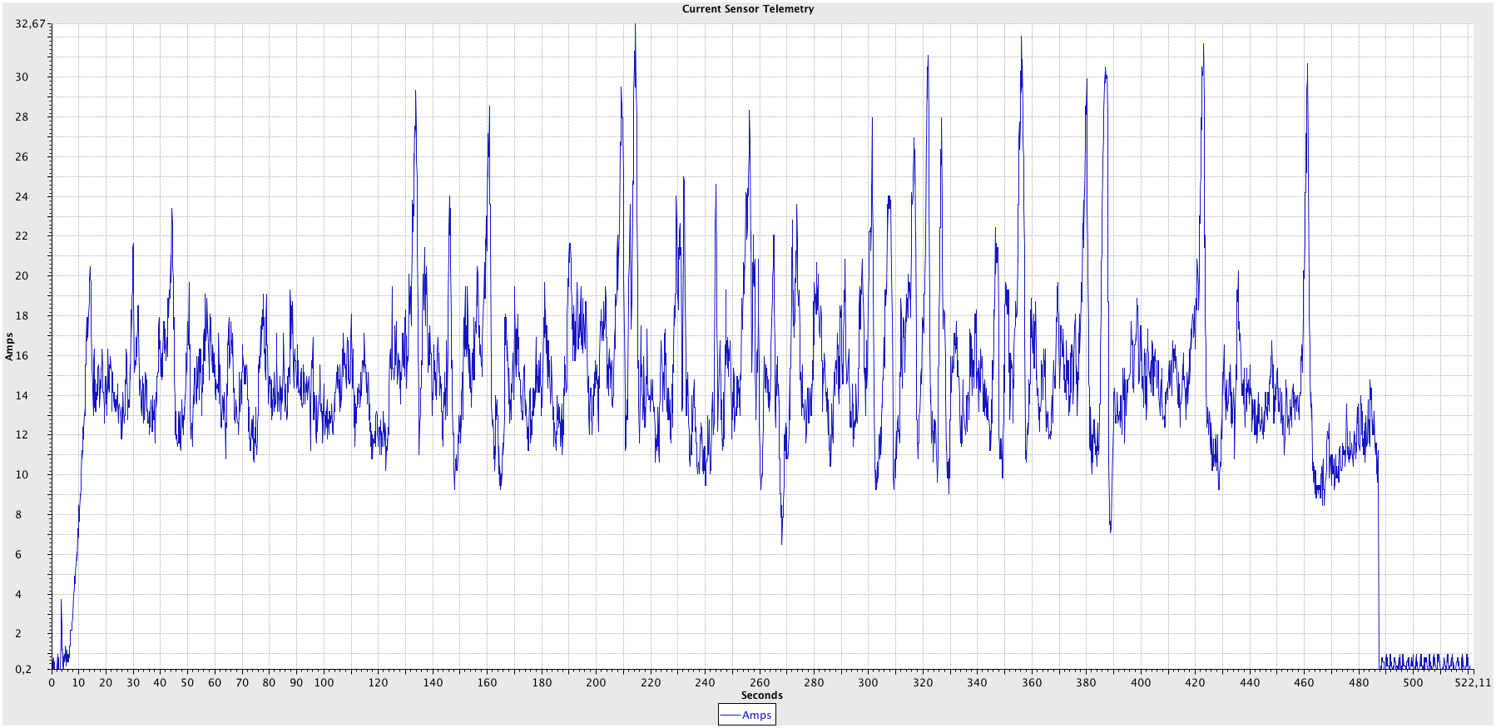
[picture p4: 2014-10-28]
flight_logs/TREX500_20141026_REVA.png

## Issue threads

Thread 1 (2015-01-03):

SpektrumTelemetrySensor.cproj

KHeintz, 2015-01-03:
Atmel Studio aborts with the following message.

spektel-sensor-master\spektel-sensor-master\project\SpektrumTelemetrySensor\SpektrumTelemetrySensor.cproj : error  : The project file could not be loaded. Could not find a part of the path. Atmel Studio missing the project file.

csc13, 2015-01-05:
Hi,
I didn't intend to give the whole project, only the source files. I'm currently finishing the changes for REV_B. So if you want a ready working version for the board REV_B, you need to wait some more days.

Does this help you?
Regards
Chris

csc13, 2015-01-19:
The project is available as a ZIP file and should be placed in the Atmel/6.2 folder.
See in the "project" folder!

Closed 2015-01-19.

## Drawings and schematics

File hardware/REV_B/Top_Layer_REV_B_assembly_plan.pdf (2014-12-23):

IC1

C4

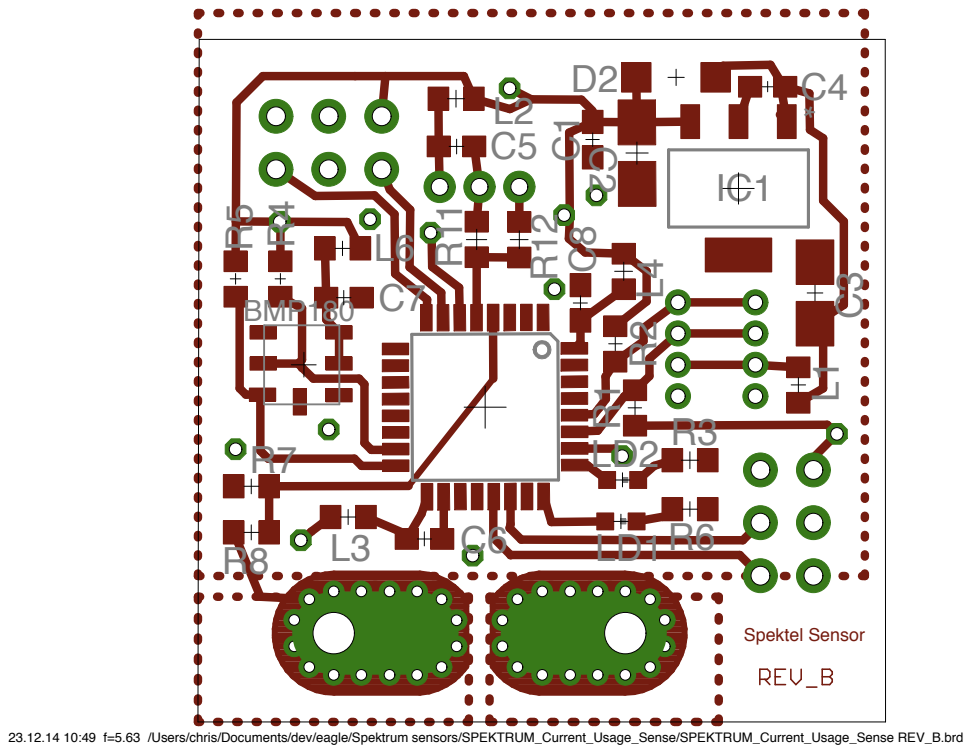
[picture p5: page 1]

23.12.14 10:49 f=5.63 /Users/chris/Documents/dev/eagle/Spektrum sensors/SPEKTRUM_Current_Usage_Sense/SPEKTRUM_Current_Usage_Sense REV_B.brd

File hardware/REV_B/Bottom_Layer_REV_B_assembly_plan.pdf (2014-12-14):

1 | 2

S1

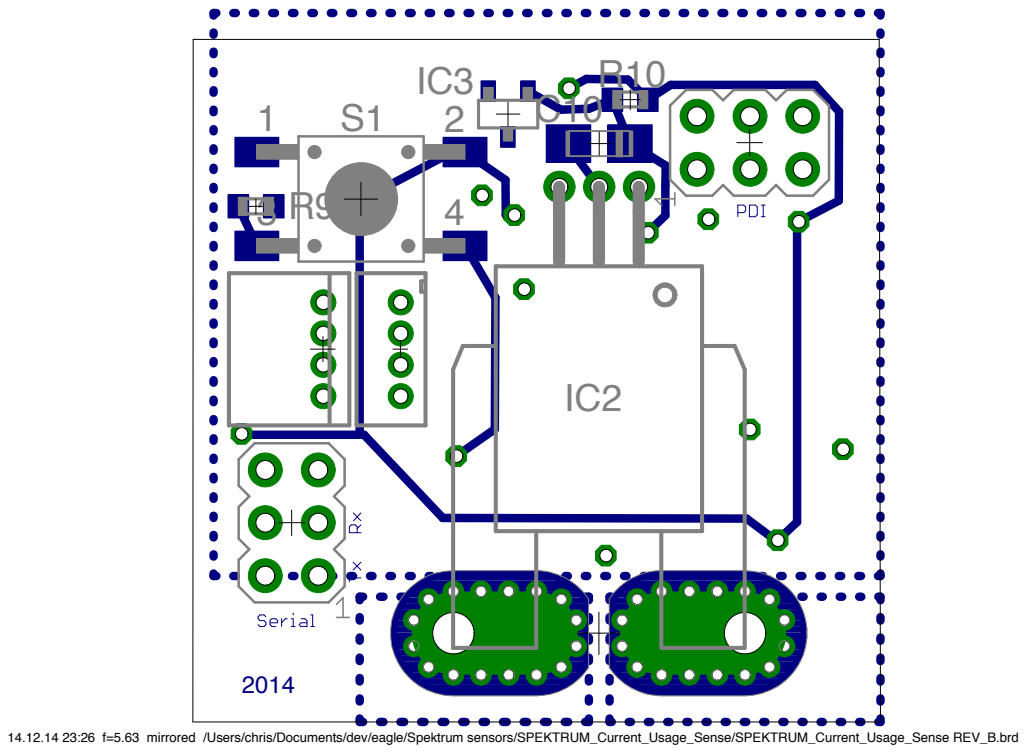
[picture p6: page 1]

14.12.14 23:26 f=5.63 mirrored /Users/chris/Documents/dev/eagle/Spektrum sensors/SPEKTRUM_Current_Usage_Sense/SPEKTRUM_Current_Usage_Sense REV_B.brd

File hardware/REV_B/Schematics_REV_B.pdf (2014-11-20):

## MCP1826S-3302E/DB

# 2.7K VCC

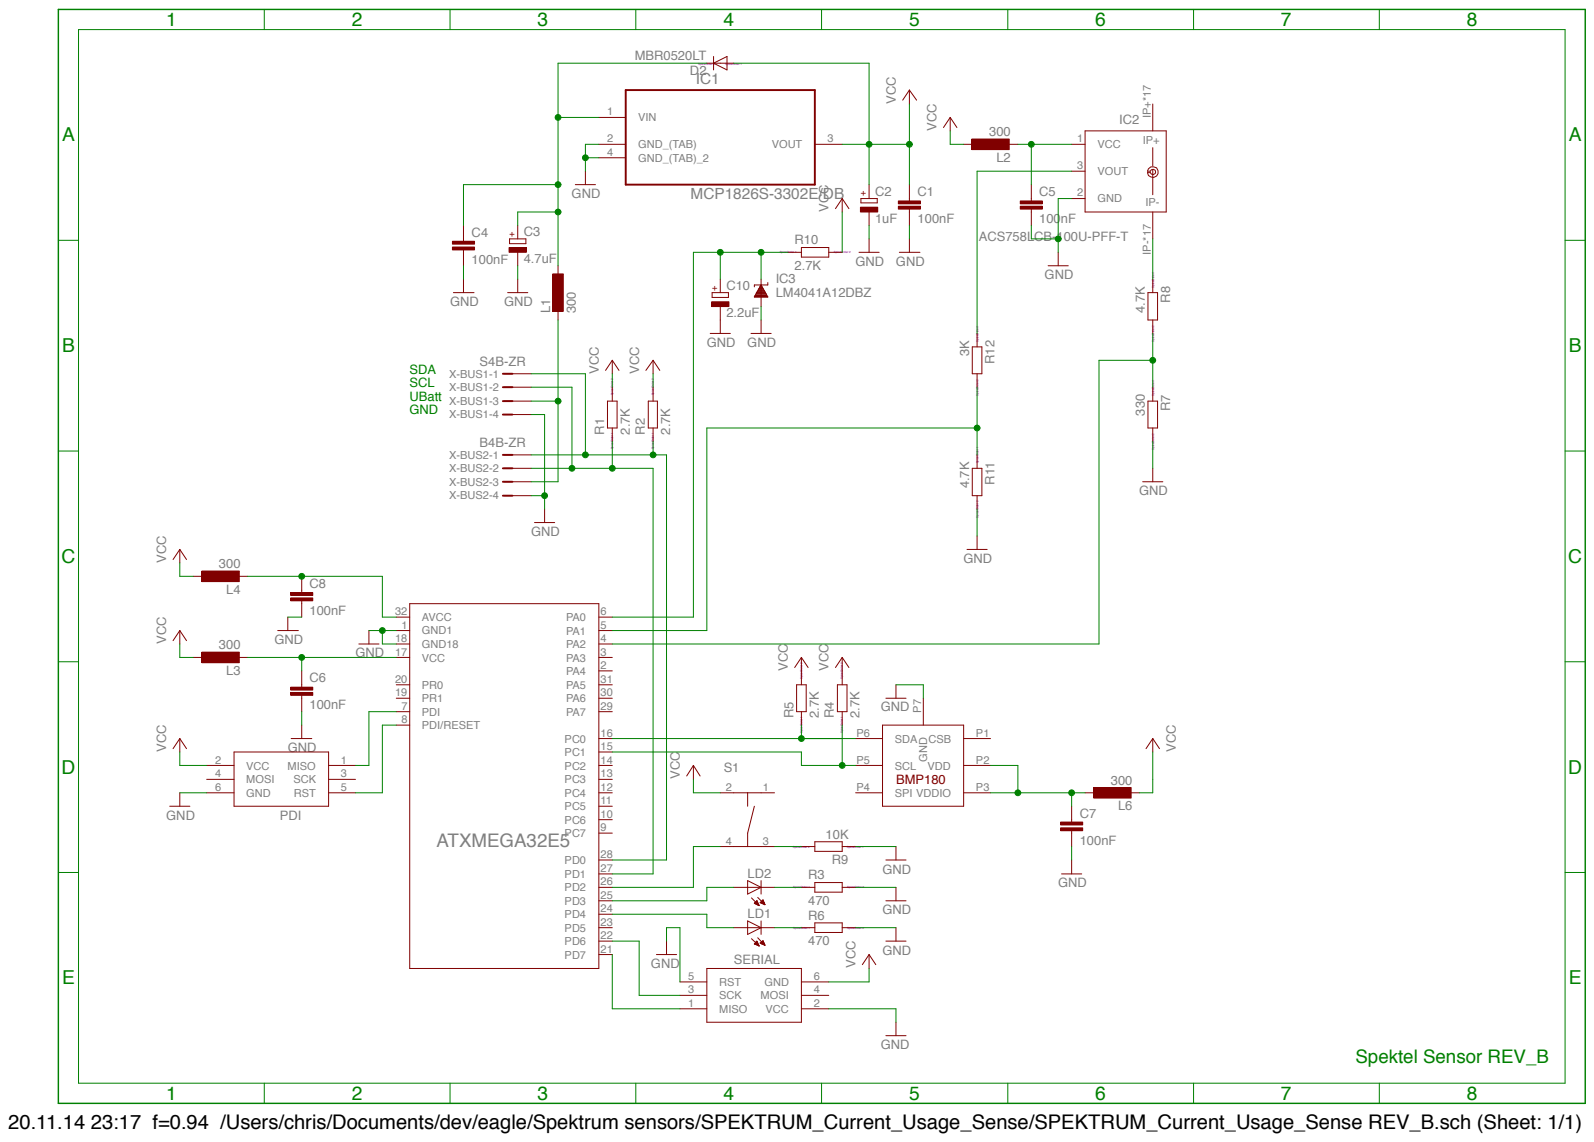
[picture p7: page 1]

SpiceOrder 1 SpiceOrder 2

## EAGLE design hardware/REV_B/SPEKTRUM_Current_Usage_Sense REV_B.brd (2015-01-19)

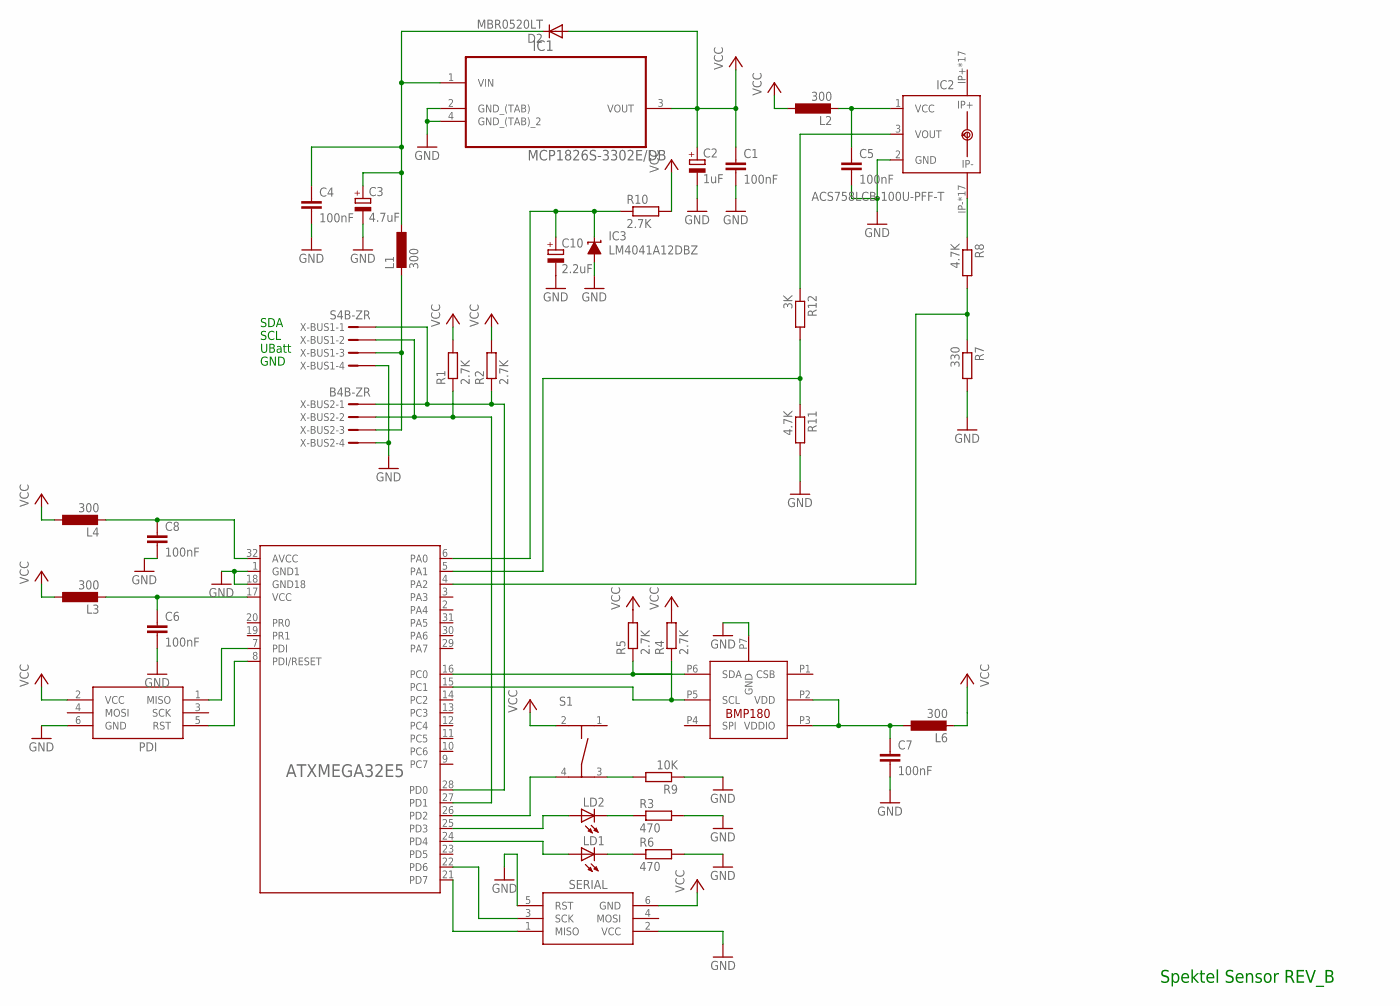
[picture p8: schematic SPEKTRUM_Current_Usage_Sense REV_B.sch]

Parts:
ATXMEGA32E5: ATXMEGA32E5/16E5/8E5ATXMEGA32E5-AU; TQFP32-08
BMP180: BMP180; BMP180_LGA7
C1, C4, C5, C6, C7, C8: 100nF; C0603
C2: 1uF; A/3216-18W
C3: 4.7uF; A/3216-18W
C10: 2.2uF; A/3216-18W
D2: MBR0520LT; SOD123
IC1: MCP1826S-3302E/DB; SOT230P700X180-4N
IC2: ACS758LCB-100U-PFF-T; CB-PFF; MPN ACS758LCB-100U-PFF-T
IC3: LM4041A12DBZ; DBZ_R-PDSO-G3
L1, L2, L3, L4, L6: 300; L0603
LD1, LD2: LEDCHIPLED_0603; CHIPLED_0603
PDI: AVRISP-6; AVRISP
R1, R2, R4, R5, R10: 2.7K; R0603
R3, R6: 470; R0603
R7: 330; R0603
R8, R11: 4.7K; R0603
R9: 10K; R0603
R12: 3K; R0603
S1: TASTER-9314_SMD
SERIAL: AVRISP-6; AVRISP
X-BUS1: S4B-ZR
X-BUS2: B4B-ZR

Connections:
ADC_CURRENT: ATXMEGA32E5.5 (PA1), R11.1, R12.2
ADC_VOLTAGE: ATXMEGA32E5.4 (PA2), R7.1, R8.2
AREF: ATXMEGA32E5.6 (PA0), C10.+, IC3.1 (C), R10.1
AVCCMC: ATXMEGA32E5.32 (AVCC), C8.1, L4.2
D_BUTTON: ATXMEGA32E5.26 (PD2), S1.4
GND: ATXMEGA32E5.1 (GND1), ATXMEGA32E5.18 (GND18), BMP180.P7 (GND), C1.2, C2.-, C3.-, C4.2, C5.2, C6.2, C7.2, C8.2, C10.-, IC1.2 (GND_(TAB)), IC1.4 (GND_(TAB)_2), IC2.2 (GND), IC3.2 (A), PDI.6 (GND), R3.2, R6.2, R7.2, R9.1, R11.2, SERIAL.2 (VCC), SERIAL.5 (RST), X-BUS1.4, X-BUS2.4
LED1: ATXMEGA32E5.24 (PD4), LD1.A
LED2: ATXMEGA32E5.25 (PD3), LD2.A
unnamed: L1.2, X-BUS1.3, X-BUS2.3
unnamed: LD2.C, R3.1
unnamed: C5.1, IC2.1 (VCC), L2.2
unnamed: LD1.C, R6.1
unnamed: BMP180.P2 (VDD), BMP180.P3 (VDDIO), C7.1, L6.1
unnamed: R9.2, S1.3
unnamed: IC2.3 (VOUT), R12.1
unnamed: ATXMEGA32E5.7 (PDI), PDI.1 (MISO)
unnamed: ATXMEGA32E5.8 (PDI/RESET), PDI.5 (RST)
RXD0: ATXMEGA32E5.22 (PD6), SERIAL.3 (SCK)
SENS_CUR_-: IC2.IP-, IC2.IP-@2 (IP-), IC2.IP-@3 (IP-), IC2.IP-@4 (IP-), IC2.IP-@5 (IP-), IC2.IP-@6 (IP-), IC2.IP-@7 (IP-), IC2.IP-@8 (IP-), IC2.IP-@9 (IP-), IC2.IP-@10 (IP-), IC2.IP-@11 (IP-), IC2.IP-@12 (IP-), IC2.IP-@13 (IP-), IC2.IP-@14 (IP-), IC2.IP-@15 (IP-), IC2.IP-@16 (IP-), IC2.IP-@17 (IP-), R8.1
TWIM_SCL: ATXMEGA32E5.15 (PC1), BMP180.P5 (SCL), R4.1
TWIM_SDA: ATXMEGA32E5.16 (PC0), BMP180.P6 (SDA), R5.1
TWIS_SCL: ATXMEGA32E5.27 (PD1), R1.1, X-BUS1.2, X-BUS2.2
TWIS_SDA: ATXMEGA32E5.28 (PD0), R2.1, X-BUS1.1, X-BUS2.1
TXD0: ATXMEGA32E5.21 (PD7), SERIAL.1 (MISO)
UBATT: C3.+, C4.1, D2.C, IC1.1 (VIN), L1.1
VCC: C1.1, C2.+, D2.A, IC1.3 (VOUT), L2.1, L3.1, L4.1, L6.2, PDI.2 (VCC), R1.2, R2.2, R4.2, R5.2, R10.2, S1.2, SERIAL.6 (GND)
VCCMC: ATXMEGA32E5.17 (VCC), C6.1, L3.2

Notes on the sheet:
SDA
SCL
UBatt
GND
Spektel Sensor REV_B

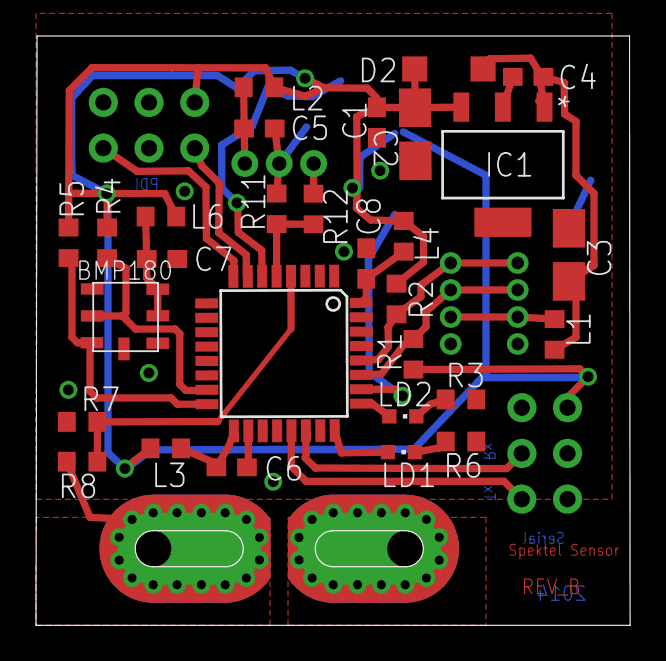
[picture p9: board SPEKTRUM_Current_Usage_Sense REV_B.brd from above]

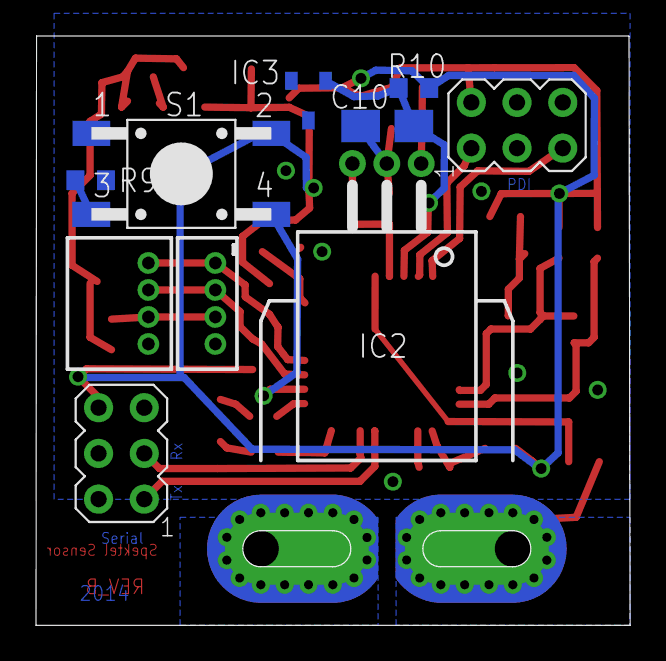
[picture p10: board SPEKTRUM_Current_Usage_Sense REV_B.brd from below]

Board: 2 copper layers, 33.0 x 32.7 mm, 39 parts (10 on the bottom side), 27 nets.

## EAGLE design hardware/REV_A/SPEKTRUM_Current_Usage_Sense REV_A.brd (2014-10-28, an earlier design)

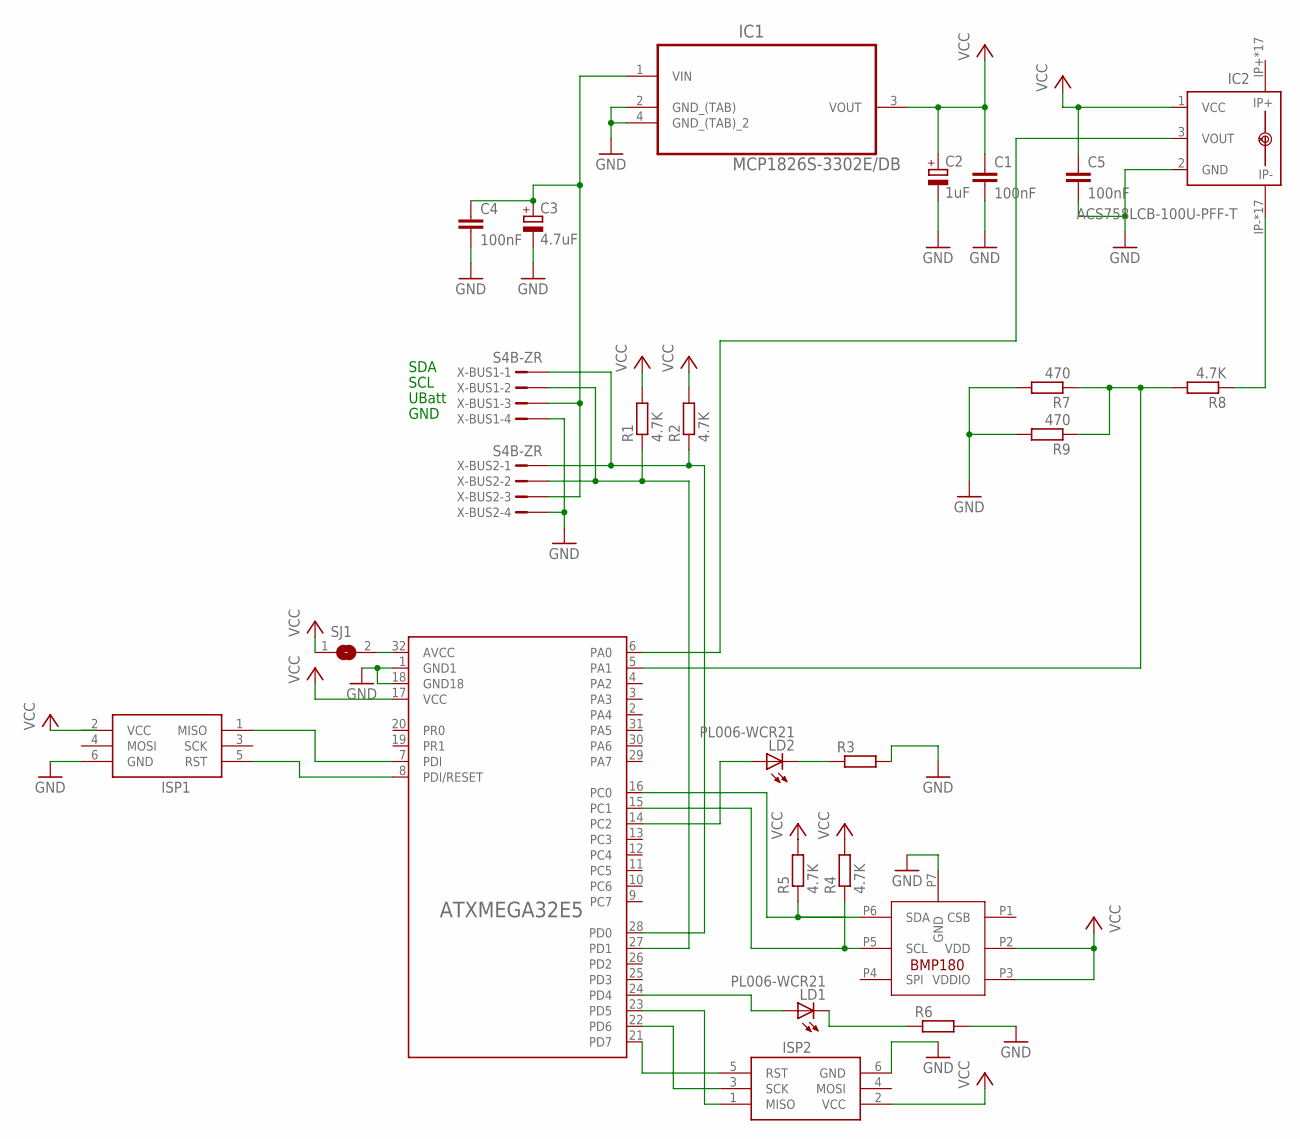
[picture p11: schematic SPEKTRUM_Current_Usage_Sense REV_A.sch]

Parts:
ATXMEGA32E5: ATXMEGA32E5/16E5/8E5ATXMEGA32E5-AU; TQFP32-08
C1, C4, C5: 100nF; C0603
C2: 1uF; A/3216-18W
C3: 4.7uF; A/3216-18W
IC1: MCP1826S-3302E/DB; SOT230P700X180-4N
IC2: ACS758LCB-100U-PFF-T; CB-PFF; MPN ACS758LCB-100U-PFF-T
ISP1, ISP2: AVRISP-6; AVRISP
LD1, LD2: PL006-WCR21; SOT23
R1, R2, R4, R5, R8: 4.7K; M1206
R3, R6: R-EU_M1206; M1206
R7, R9: 470; M1206
SJ1: SJ
U$1: BMP180; BMP180_LGA7
X-BUS1, X-BUS2: S4B-ZR

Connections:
GND: ATXMEGA32E5.1 (GND1), ATXMEGA32E5.18 (GND18), C1.2, C2.-, C3.-, C4.2, C5.2, IC1.2 (GND_(TAB)), IC1.4 (GND_(TAB)_2), IC2.2 (GND), ISP1.6 (GND), ISP2.6 (GND), R3.2, R6.2, R7.2, R9.2, U$1.P7 (GND), X-BUS1.4, X-BUS2.4
unnamed: ATXMEGA32E5.6 (PA0), IC2.3 (VOUT)
unnamed: C3.+, C4.1, IC1.1 (VIN), X-BUS1.3, X-BUS2.3
unnamed: LD2.1 (C), R3.1
unnamed: ATXMEGA32E5.27 (PD1), R1.1, X-BUS1.2, X-BUS2.2
unnamed: ATXMEGA32E5.28 (PD0), R2.1, X-BUS1.1, X-BUS2.1
unnamed: LD1.1 (C), R6.1
unnamed: ATXMEGA32E5.14 (PC2), LD2.3 (A)
unnamed: ATXMEGA32E5.16 (PC0), R5.1, U$1.P6 (SDA)
unnamed: ATXMEGA32E5.15 (PC1), R4.1, U$1.P5 (SCL)
unnamed: ATXMEGA32E5.7 (PDI), ISP1.1 (MISO)
unnamed: ATXMEGA32E5.8 (PDI/RESET), ISP1.5 (RST)
unnamed: ATXMEGA32E5.24 (PD4), LD1.3 (A)
unnamed: ATXMEGA32E5.32 (AVCC), SJ1.2
unnamed: IC2.IP-, IC2.IP-@2 (IP-), IC2.IP-@3 (IP-), IC2.IP-@4 (IP-), IC2.IP-@5 (IP-), IC2.IP-@6 (IP-), IC2.IP-@7 (IP-), IC2.IP-@8 (IP-), IC2.IP-@9 (IP-), IC2.IP-@10 (IP-), IC2.IP-@11 (IP-), IC2.IP-@12 (IP-), IC2.IP-@13 (IP-), IC2.IP-@14 (IP-), IC2.IP-@15 (IP-), IC2.IP-@16 (IP-), IC2.IP-@17 (IP-), R8.1
unnamed: ATXMEGA32E5.5 (PA1), R7.1, R8.2, R9.1
unnamed: ATXMEGA32E5.21 (PD7), ISP2.5 (RST)
unnamed: ATXMEGA32E5.22 (PD6), ISP2.3 (SCK)
unnamed: ATXMEGA32E5.23 (PD5), ISP2.1 (MISO)
VCC: ATXMEGA32E5.17 (VCC), C1.1, C2.+, C5.1, IC1.3 (VOUT), IC2.1 (VCC), ISP1.2 (VCC), ISP2.2 (VCC), R1.2, R2.2, R4.2, R5.2, SJ1.1, U$1.P2 (VDD), U$1.P3 (VDDIO)

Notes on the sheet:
SDA
SCL
UBatt
GND

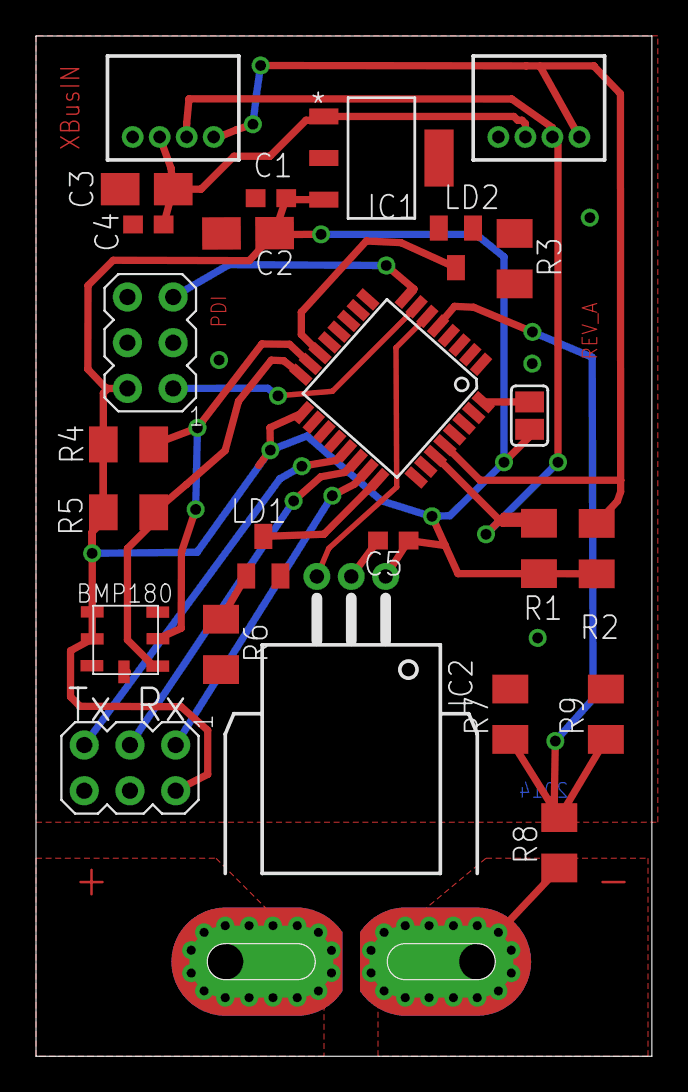
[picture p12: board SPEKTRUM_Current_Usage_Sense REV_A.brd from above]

Board: 2 copper layers, 34.2 x 56.7 mm, 25 parts (0 on the bottom side), 20 nets.

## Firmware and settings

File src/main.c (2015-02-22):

/**
 * \file
 *
 * \brief Spektrum RC Telemetry AllinOne Sensor
 *
 */

/**
 * \mainpage Spektrum RC Telemetry All-In-One Sensor
 *
 * \par Target functionality
 *
 * The Spektrum RC Telemetry All-In-One Sensor is a Atmel ATXMEGA32E5-U
 * based sensor board using the Spektrum XBus to communicate with the 
 * Spektrum RC telemetry module TM1000. The TM1000 is used to send the
 * telemetry informations to the RC transmitter.
 * Thanks to contributions in a RC-Goups forum (special thanks to Mukenukem),
 * the I2C/TWI based XBus protocol is known. This software and the corresponding
 * hardware was inspired by the ideas of many forum contributors.
 *
 * The target is to create a platform for DIY Spektrum RC multi-sensors, combining
 * several sensor functions in a space saving application. An important target
 * was to provide a flexible capacity sensor and alarm for relative small models.
 *
 * \par Features
 *
 * -# XBus / TWI slave support for TM1000
 * -# eFuel Gauge - Used capacity sensor (as Spektrum RC Powerbox sensor)
 * -# Capacity alarm - underun battery 80% capacity
 * -# Main battery voltage
 * -# Voltage alarm by low watermark
 * -# Ampere meter (as Sketrum Ampere sensor)
 * -# Altitude meter (as Spektrum RC Vario sensor)
 * -# Climb rate sensor (as Spektrum RC Vario sensor)
 * -# Basic USART connector
 *
 * \par Possible future features
 * -# Programmable via USB
 * -# XBus In and Out connector for daisy chaining connectors (TODO: software support)
 * -# Cell voltage measurements, control and alarm
 * -# Other sensor support
 *
 *  \par Modules
 *
 * -# spektel - Spektrum RC TM1000 XBus/TWI based communication
 * -# adc_sens - Analog signal based sensor inputs (like ACS758 hall sensor, battery main voltage, etc.)
 * -# bmp180_sens - Bosch BMP180 air pressure sensor
 *
 *  \par Configuration
 *
 * -# conf_board.h is used to configure the used board revision and hardware
 * -# conf_spektel.h is used to configure the used Spektrum RC sensors based on the transmitter
 */

/*
 * The application uses the Atmel ASF framework.
 * The project is a DIY sample and has no commercial background.
Disclaimer for this application
The use of this software and is intended for hobby use only and no liability for any loss or damage is taken in any aspect.
The use is totally on own risk.

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
1. Redistributions of source code must retain the above copyright notice, this list of conditions and the following
disclaimer.

2. Redistributions in binary form must reproduce the above copyright notice, this list of conditions and the following
disclaimer in the documentation and/or other materials provided with the distribution.

3. The name of Atmel may not be used to endorse or promote products derived from this software without specific
prior written permission.

4. This software may only be redistributed and used in connection with an Atmel microcontroller product.

THIS SOFTWARE IS PROVIDED BY ATMEL "AS IS" AND ANY EXPRESS OR IMPLIED WARRANTIES,
INCLUDING, BUT NOT LIMITED TO, THE IMPLIED WARRANTIES OF MERCHANTABILITY, FITNESS FOR A
PARTICULAR PURPOSE AND NON-INFRINGEMENT ARE EXPRESSLY AND SPECIFICALLY DISCLAIMED. IN
NO EVENT SHALL ATMEL BE LIABLE FOR ANY DIRECT, INDIRECT, INCIDENTAL, SPECIAL, EXEMPLARY,
OR CONSEQUENTIAL DAMAGES (INCLUDING, BUT NOT LIMITED TO, PROCUREMENT OF SUBSTITUTE
GOODS OR SERVICES; LOSS OF USE, DATA, OR PROFITS; OR BUSINESS INTERRUPTION) HOWEVER
CAUSED AND ON ANY THEORY OF LIABILITY, WHETHER IN CONTRACT, STRICT LIABILITY, OR TORT
(INCLUDING NEGLIGENCE OR OTHERWISE) ARISING IN ANY WAY OUT OF THE USE OF THIS SOFTWARE,
EVEN IF ADVISED OF THE POSSIBILITY OF SUCH DAMAGE.
*/

#include <asf.h>
#include <stdio.h>

#include "spektel.h"
#include "bmp180.h"
#include "floating_average.h"
#include "filter.h"
#include "filter_32.h"
#include "setup.h"
#include "calc_measure.h"

// ADC measurement data structures
volatile bool measure_cycle = false;
struct adc_channel_config adcch_conf;
uint16_t cur_mea_val = 0; //latest measurement
uint16_t vol_mea_val = 0; //latest measurement

// floating average data structures
tFloatAvgFilter cur_filter1 = { {0}, 0 };  //filter level 1
tFloatAvgFilter cur_filter2 = { {0}, 0 };  //filter level 2
tFloatAvgFilter cur_filter3 = { {0}, 0 };  //filter level 3
	
//simple lowpass filter	for voltage
tSimpleLowpassReg lowpass_reg_volt = { 0, 0 };
	
//simple lowpass filter for pressure	
tSimpleLowpassReg32 lowpass_reg_prs = { 0, 0 };
bool startup = true;
uint8_t sample_count = 0; //Counts samples in cycles of 255 for temperature measurements	
		
// variables for capacity calculation
uint16_t cur_adc_res[2] = { ADC_B, ADC_B }; // This is power = 0
uint32_t time[2] = { 0 };
bool act = 0;
uint32_t cap_mAms = 0;
uint16_t cap_mAh = 0;
uint16_t cap_min = 0;

// variables for climb rate calculation
int32_t cl_prs[2] = {0, 0};
int32_t alt_dif = 0;	
	
// Spektrum RC data structures	
volatile spektel_sensor_current_t cur = { 0 };
volatile spektel_sensor_powerbox_t power = { 0 };
volatile spektel_sensor_vario_t vario = { 0 };
volatile spektel_sensor_flight_cap_t flight_cap = { 0 };

static void evsys_init(void) {
	sysclk_enable_module(SYSCLK_PORT_GEN, SYSCLK_EVSYS);
}

static void tc_error_callback(void) {
	ioport_set_pin_level(LED_GREEN, 0);
}

static void tc_overflow_callback(void) {
	tc45_clear_overflow(&TIMER_SENS);
}

/*
static void tc_cca_callback(void) {
} */

static void tc_init(void)
{
	/* Unmask clock for TCC4 */
	tc45_enable(&TIMER_SENS);

	/* Configure TC in normal mode */
	tc45_set_wgm(&TIMER_SENS, TC45_WG_NORMAL);

	/* Configure period*/
	tc45_write_period(&TIMER_SENS, TIMER_SENS_RESOLUTION / TIMER_SENS_PER);

	/* Configure CCA to occur at half the period */
	tc45_write_cc(&TIMER_SENS, TC45_CCA, TIMER_SENS_RESOLUTION / TIMER_SENS_PER / 2);

	/* Enable CCA channels */
	tc45_enable_cc_channels(&TIMER_SENS, TC45_CCACOMP);
	
	tc45_set_error_interrupt_callback(&TIMER_SENS, *tc_error_callback);
	tc45_set_overflow_interrupt_callback(&TIMER_SENS, *tc_overflow_callback);
	//tc45_set_cca_interrupt_callback(&TIMER_SENS, *tc_cca_callback);
	
	tc45_set_error_interrupt_level(&TIMER_SENS, TC45_INT_LVL_LO);
	tc45_set_overflow_interrupt_level(&TIMER_SENS, TC45_INT_LVL_LO);
	tc45_set_cca_interrupt_level(&TIMER_SENS, TC45_INT_LVL_LO);
}

static void adc_cur_callback(ADC_t *adc, uint8_t ch_mask, adc_result_t res) {
	cur_mea_val = res;
	act = !act;
	time[act] = rtc_get_time();
	
	measure_cycle = true;	
}

static void adcch_set_cur_measure(void) {
	// Set ADC to ACS current pin and interrupt
	adcch_set_input(&adcch_conf, ADC_MAIN_CURRENT_PIN, ADCCH_NEG_NONE, 1);
	adcch_enable_averaging(&adcch_conf, ADC_CUR_AVERAG_SAMP);
	adcch_set_interrupt_mode(&adcch_conf, ADCCH_MODE_COMPLETE); //complete conversion
	//adcch_conf.intctrl |= 0x10; //set via conf_adc.h to MED
	adcch_enable_interrupt(&adcch_conf);
}

static uint16_t adcch_get_pin_measure(enum adcch_positive_input pin, enum adcch_sampnum sample) {
	// Set ADC channel to voltage pin measurement
	// Set ADC to ACS current pin and interrupt
	adcch_set_input(&adcch_conf, pin, ADCCH_NEG_NONE, 1);
	adcch_enable_averaging(&adcch_conf, sample);
	//adcch_set_interrupt_mode(&adcch_conf, ADCCH_MODE_COMPLETE); //complete conversion
	//adcch_conf.intctrl |= 0x10; //set via conf_adc.h to MED
	adcch_disable_interrupt(&adcch_conf);
	adcch_write_configuration(&ADC_MAIN, ADC_MAIN_CH, &adcch_conf);

	// Start ADC measurement
	adc_start_conversion(&ADC_MAIN, ADC_MAIN_CH);
	adc_wait_for_interrupt_flag(&ADC_MAIN, ADC_MAIN_CH);
	
	return adc_get_unsigned_result(&ADC_MAIN, ADC_MAIN_CH);	
}

static void adc_init(void) {
	static struct adc_config adc_conf;
	adc_read_configuration(&ADC_MAIN, &adc_conf);
	adcch_read_configuration(&ADC_MAIN,ADC_MAIN_CH, &adcch_conf);
	 
	// Set Unsigned mode, 12bit resolution REF Voltage to Vcc / 1.6 = 2.06V
	adc_set_conversion_parameters(&adc_conf, ADC_SIGN_OFF,ADC_RES_MT12 , ADC_REF_VCC);  // ADC_RES_12
	adc_set_conversion_trigger(&adc_conf, ADC_TRIG_EVENT_SYNCSWEEP,1, 3 );
	adc_set_clock_rate(&adc_conf, ADC_CLOCK); // ADC clock 1.8MHz
	adc_set_callback(&ADC_MAIN, *adc_cur_callback);
	
	adcch_set_cur_measure();
	
	adc_write_configuration(&ADC_MAIN, &adc_conf);
	adcch_write_configuration(&ADC_MAIN, ADC_MAIN_CH, &adcch_conf);
	
	adc_enable(&ADC_MAIN);
}

static void calibration(void) {
	// Initialize floating average filters
	InitFloatAvg(&cur_filter1,  adcch_get_pin_measure(ADC_MAIN_VOLTAGE_PIN, ADC_VOLT_AVERAG_SAMP));   // Read the value for 0V voltage
	//InitFloatAvg(&cur_filter2, adcch_get_pin_measure(ADC_MAIN_REF_VOLTAGE_PIN, ADC_REF_AVERAG_SAMP)); // Read the value for 2,048V voltage
	InitFloatAvg(&cur_filter3, adcch_get_pin_measure(ADC_MAIN_CURRENT_PIN, ADC_CUR_AVERAG_SAMP));     // Read the value for 0A current
	
	for(uint8_t i = 0; i < 40 ; i++) {
		AddToFloatAvg(&cur_filter1, adcch_get_pin_measure(ADC_MAIN_VOLTAGE_PIN, ADC_VOLT_AVERAG_SAMP)); // Read the value for 0V voltage
		//AddToFloatAvg(&cur_filter2, adcch_get_pin_measure(ADC_MAIN_REF_VOLTAGE_PIN, ADC_REF_AVERAG_SAMP)); // Read the value for 2,048V voltage
		AddToFloatAvg(&cur_filter3, adcch_get_pin_measure(ADC_MAIN_CURRENT_PIN, ADC_CUR_AVERAG_SAMP)); // Read the value for 0A current
	}
	
	uint16_t volt_zero = GetOutputValue(&cur_filter1);   // value for 0V voltage
	//uint16_t volt_ref = GetOutputValue(&cur_filter2);    // value for 2,048V voltage
	uint16_t ACS758_zero = GetOutputValue(&cur_filter3); // value for 0A current
	
	//double lsb_res = 2.048D / (double)(volt_ref - volt_zero);	
	saveCalibration(ACS758_zero + 1, volt_zero);
}


static void plotter_init(void) {
	#if ARDUPLOT
		printf("\nd %u %u %u %u %u %u %d %d\n", cur.current, power.volt1, power.volt2, power.cap1, power.cap2, cur_mea_val, vario.altitude, vario.climb_rate_250ms);
		printf("n current volt1 volt2 cap1 cap2 measure, altitude, climbrt\n");
		printf("r current 0 5000 volt1 0 2600 volt2 0 2600 cap1 0 3000 cap2 0 55000 measure 0 4096 altitude -2000 2000 climbrt -200 200\n");
		printf("c current 255 255 255 volt1 0 0 255 volt2 0 255 0 cap1 255 0 0 cap2 0 255 255 measure 150 150 0 altitude 255 150 150 climbrt 150 255 150\n");
	#endif
}

static void writeToPlotter(void) {
	#if ARDUPLOT
		printf("d %u %u %u %u %u %u %d %d\n", cur.current, power.volt1, power.volt2, power.cap1, power.cap2, cur_mea_val, vario.altitude, vario.climb_rate_250ms);
	#elif REALTIME_PLOTTER
		printf("%u %u %u %u %u %u %d %d\r", cur.current, power.volt1, power.volt2, power.cap1, power.cap2, cur_mea_val, vario.altitude, vario.climb_rate_250ms);
	#endif
}

int main (void)
{
	sysclk_init();
	board_init();
	sleepmgr_init();
	rtc_init();
	
	cli();
	
	spektel_init();
			
	evsys_init();
	tc_init();
	adc_init();
		
	EVSYS.CH3MUX = EVSYS_CHMUX_TCC4_CCA_gc;  //Connect TCC4 Compare interrupt to event channel 3 (used to trigger ADC)
	tc45_set_resolution(&TIMER_SENS, TIMER_SENS_RESOLUTION);

	sei();
	
	irq_initialize_vectors();
	cpu_irq_enable();
	
	// Initialize BMP180 module
	bmp180_init();
		
	// set LEDs
	ioport_set_pin_level(LED_GREEN, 1);
	ioport_set_pin_level(LED_RED, 0);
	
	// If button is pressed on startup enter setup mode
	 if( ioport_get_pin_level(BUT_1) == true ) { 
		 button_setup();
		 calibration();
	 }
	 
	 // Read calibration values
	 uint16_t _adc_b = read_adc_b();
	 uint16_t _adc_usig_base = read_adc_usig_base();
	 
	 if(_adc_b > 400 && _adc_b < 800 && _adc_usig_base > 80 && _adc_usig_base < 300) {
		init_calc(_adc_b, _adc_usig_base);
	 }
	
	// Initialize capacity output
	power.cap1 = readCapa();
	if(power.cap1 == 0 || power.cap1 == 0xFFFF) {
		power.cap1 = BAT_CAP; }
	
	spektel_write_powerbox_sens(power);
	cap_min = BAT_CAP * 0.2;  //calculate bat_mi alarm level to 20% capacity left
	
	// Initialize floating average filters
	InitFloatAvg(&cur_filter1, ACS_B);
	InitFloatAvg(&cur_filter2, ACS_B);
	InitFloatAvg(&cur_filter3, ACS_B);
	
	// Initialize simple lowpass filter for voltage
	init_simple_lowpass(&lowpass_reg_volt, 4);
	
	// Initialize simple lowpass filter for altitude
	init_simple_lowpass_32(&lowpass_reg_prs, 5);
	
	//Start first pressure measurement
	bmp180_start_pressure_measurement();
	
	// Initialize plotter
	plotter_init();

	while(1) {
				
		sleepmgr_enter_sleep(); //sleep up to next interrupt
		
		// Check if this is a wake up from the ADC current measurement. There will be a lot of TWI interrupts
		if(measure_cycle) {
			//filter
			AddToFloatAvg(&cur_filter1, (cur_mea_val));
			AddToFloatAvg(&cur_filter2, GetOutputValue(&cur_filter1));
			AddToFloatAvg(&cur_filter3, GetOutputValue(&cur_filter2));
			cur_adc_res[act] = (GetOutputValue(&cur_filter3));	
			
			// finish capacity and current calculations
			cap_mAms += calc_cap_mAms( cur_adc_res[!act], cur_adc_res[act], time[!act], time[act] );
			cur.current = calc_mA(cur_adc_res[act]);
			flight_cap.current = cur.current / 10;
			power.cap2 = cur.current * 10;
			
			//power.volt2 = cur_adc_res[act];
			
			//Check for capacity overflow
			if( cap_mAms >= 3600000 ) {
				cap_mAms -= 3600000;  //- one mAh
				cap_mAh++;			  //+ one mAh
				flight_cap.cap = cap_mAh; //set capa used for flight pack capacity sensor
				power.cap1--;         //subtract from capacity output
				//Check for alarm: under BAT_MIN (for powerbox sensor only)
				if( power.cap1 <= cap_min ) {
					power.cap1_alarm = true;
				}
			}

			// Get main battery voltage pin measure
			power.volt1 = calc_main_mV(simple_lowpass(&lowpass_reg_volt, adcch_get_pin_measure(ADC_MAIN_VOLTAGE_PIN, ADC_VOLT_AVERAG_SAMP)));
			
			// ADC channel back to current measurement and enable interrupt
			adcch_set_cur_measure();
			adcch_write_configuration(&ADC_MAIN, ADC_MAIN_CH, &adcch_conf);
			
			// The BMP180 requires measuring and reading the actual temperature from the device for temp. drift compensation
			// So we do a temperature reading every 32nd measurement. We use a rolling counter
			if((sample_count & 0x3F) == 0x3F) {
				bmp180_calc_temperature();
				flight_cap.temp = (int16_t)bmp180_get_temperature(); //This is the environment temperature, not the temperature of the flight pack!
			}
			else {
				// Read and calculate pressure from BMP180
				bmp180_calc_pressure();  //Read and calculate last measurement from BMP180
				cl_prs[act] = simple_lowpass_32(&lowpass_reg_prs, get_pressure()); //Use a low pass for the pressure
				vario.altitude = calc_altitude(cl_prs[act]);
				
				if((sample_count == 0xFF) && startup) {
					set_base_pressure(cl_prs[act]);
					startup = false;
				}
				
				// Climb rate is
				// (Actual hight - Last hight) / time in seconds
				/*alt_dif = ((int32_t)(cl_prs[act] - cl_prs[!act])) * 1000;
				if( alt_dif != 0 ) {
					alt_dif = alt_dif / ((int32_t)(time[act] - time[!act]));
					vario.climb_rate = simple_lowpass(&lowpass_reg_clbrt, (int16_t)alt_dif );
				}*/
			}
			
			
			sample_count++; //overrun is wanted	
			// Trigger the next measurement of the BMP180
			if((sample_count & 0x3F) == 0x3F) {
				bmp180_start_temperature_measurement();
			}
			else {
				bmp180_start_pressure_measurement(); //Since the measure cycle is triggered every 40ms its enough time for the BMP180 in ultrahigh precision mode
			}
					
			measure_cycle = false;
		
			// write the values out
			spektel_write_flight_cap_sens(flight_cap);
			spektel_write_powerbox_sens(power);
			spektel_write_current_sens(cur);
			spektel_write_vario_sens(vario);
			
			 writeToPlotter();
		}	
		
			 if( ioport_get_pin_level(BUT_1) == true ) {
				 set_base_pressure(cl_prs[act]);
			 }
	}
	
/* code for Spektrum XBus monitoring via LED
		ioport_set_pin_level(LED_GREEN, !spektel_getStatus());
		r = spektel_getResult();
		if( r == TWIS_RESULT_OK ) {
			ioport_set_pin_level(LED_RED, 0);
		}
		else {
			ioport_set_pin_level(LED_RED, 1);
			if( r != rlast) {
				printf("Result status changed: %x", r);
				rlast = r;
			}
		}			
		
	}		*/
}

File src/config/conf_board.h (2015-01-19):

/**
 * \file
 *
 * \brief User board configuration template
 *
 */

#ifndef CONF_BOARD_H
#define CONF_BOARD_H

#define BOARD_REV_B

#define REALTIME_PLOTTER true

//#define ARDUPLOT true

#if (ARDUPLOT || REALTIME_PLOTTER)
	#define ENABLE_USART true
#endif	
  
  #ifdef BOARD_REV_B
  /*** Changes to REV_B
	* Changed pins for LEDS
	* Changed ADC pins to add VREF
	* Voltage divider for the hall sensor
	* Additional 2048V external reference voltage
 */
// TWIM for BMP180
	 #define TWI_MASTER       TWIC
	 #define TWI_MASTER_PORT  PORTC
	 #define TWI_MASTER_ADDR  0x50
	 #define TWI_SPEED        50000
	 
// TWIS for XBUS
	 #define TWI_SLAVE        TWIC
	 #define TWI_SLAVE_PORT  PORTD


// USART
	#define PR_USART1_bm  0xC0  /* Port D USART1 bit mask. */
	#define PR_USART1_bp  128  /* Port D USART1 bit position. */
	#define USARTD_REMAP 0x10  /* USART0 Remap from Px[3:0] to Px[7:4], (for additional TC4D from Px3 to Px7 and TC4C from Px2 to Px6 --> set 0x1C)*/
	
// LEDs
	#define LED_GREEN IOPORT_CREATE_PIN(PORTD, 4)
	#define LED_RED IOPORT_CREATE_PIN(PORTD, 3)
	
// Button
	#define BUT_1 IOPORT_CREATE_PIN(PORTD, 2)
	
//EEPROM
	#define CONFIG_PAGE 1
	#define CONFIG_ADDR CONFIG_PAGE * EEPROM_PAGE_SIZE
	
	#define CALIBRATION_PAGE 2
	#define CALIBRATION_ADDR CALIBRATION_PAGE * EEPROM_PAGE_SIZE	
	
// ADCs
	#define ADC_MAIN    ADCA
	#define ADC_MAIN_CH ADC_CH0 // since the XMEGA_E has only one ADC channel
	//#define ADC_MAIN_VOLTAGE_CH ADC_CH1
	#define ADC_MAIN_REF_VOLTAGE_PIN ADCCH_POS_PIN0
	#define ADC_MAIN_CURRENT_PIN ADCCH_POS_PIN1
	#define ADC_MAIN_VOLTAGE_PIN ADCCH_POS_PIN2
	
	#define ADC_CLOCK      1800000  //1.8MHz 
	#define ADC_CUR_AVERAG_SAMP ADC_SAMPNUM_8X
	#define ADC_VOLT_AVERAG_SAMP ADC_SAMPNUM_8X
	#define ADC_REF_AVERAG_SAMP ADC_SAMPNUM_8X
	#define ADC_USIG_BASE  161  // ADC result for zero voltage at pin for unsigned mode, 205 by datasheet
	#define ADC_MV_12RES		0.4899  //mV per LSB at 12 bit resolution
	
	//REV_B has voltage dividers:
	//For current measurement (3K + 4.7K) / 4.7K = 1.64
	//#define CUR_RES_DIV		1.638 //Multiply voltage with
	//By measurement of resistors
	#define CUR_RES_DIV    1.684
	   
	//For voltage measurement(4.7K + 330) / 330
	#define MAIN_RES_DIV	15.24 // (R1+R2) / R2, R1 = 4K7, R2 = 330 = 15.24
    

	/* Calculation of  current is
	 I = (((RES - ADC_USIG_BASE) * ADC_MV_12RES) - ACS758_BASE) / ACS758_RATE
	 I = ((RES - ADC_USIG_BASE) - (ACS758_BASE / ADC_MV_12RES)) * (ADC_MV_12RES / ACS758_RATE)
	 I = ((RES - ADC_USIG_BASE) - ACS_B) * (ADC_MV_12RES / ACS758_RATE)
	 I = ((RES - ADC_B) * ACS_R(_M)
	 I = (((RES - ADC_B) * ACS_R(_M)_O) >> ACS_SHIFT(_M)
	*/ 
 	
	#define ACS758_U100 
	#ifdef  ACS758_U100  
		#define ACS758_BASE		383		// mV at 0mA current at Vcc 3.3V (396 by data sheet at Vcc 3.3V)
		#define ACS758_RATE		24	    // mV/A	(at 3.3V)
		#define ACS758_RATE_M1	0.24	// mV/10mA	(at 3.3V)
		#define ACS758_RATE_M	0.024	// mV/mA	(at 3.3V)
				
		#define ACS_B			471 	//(ACS758_BASE / ADC_MV_12RES / CUR_RES_DIV)  
		#define ADC_B			632 	//(ADC_USIG_BASE + ACS_B) // Measurement 632
				
		#define ACS_R			0.0312  //(ADC_MV_12RES / ACS758_RATE * CUR_RES_DIV)
		#define ACS_R_M1		3.12	//(ADC_MV_12RES / ACS758_RATE_M1 * CUR_RES_DIV)
		#define ACS_R_M			31.2	//(ADC_MV_12RES / ACS758_RATE_M * CUR_RES_DIV)
				
		#define ACS_R_O			8.279 	// ACS_R * 256
		#define ACS_R_M1_O		3199	// ACS_R_M1 * 1024
		#define ACS_R_M_O		15996	// ACS_R_M * 512  for 32bit and max 40ms sample time only
				
		#define ACS_SHIFT		8		// /256
		#define ACS_SHIFT_M1	10		// /1024
		#define ACS_SHIFT_M		9		// /512
	#endif
  #endif
  	

// Timer
	#define TIMER_SENS	   TCC4
	#define TIMER_SENS_RESOLUTION	31250
	#define TIMER_SENS_PER 25 // 25Hz Samples(time between samples 40ms)
	//#define TIMER_SENS_PER 50 // 50Hz Samples(time between samples 20ms)

#endif // CONF_BOARD_H

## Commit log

2014-10-28 Initial upload of project
    Initial upload with BOARD REV_A
    [Calculation ACS578 Measurement.xlsx, SPEKTRUM_Current_Usage_Sense REV_A.brd, SPEKTRUM_Current_Usage_Sense REV_A.sch]
2014-10-28 Added picture of sensor
2014-10-28 Added png images for PCB layout and schematics
    [Calculation ACS578 Measurement.xlsx, SPEKTRUM_Current_Usage_Sense REV_A.brd, SPEKTRUM_Current_Usage_Sense REV_A.sch]
2014-10-31 Added lowpass filter for testing
2014-11-02 Added filtering
    Added lowpass to voltage measurement
    Corrected measurements by adding 10% to current measurement after test
    flight.
    [conf_board.h, main.c]
2014-11-20 New board revision B
    [SPEKTRUM_Current_Usage_Sense REV_B.brd, SPEKTRUM_Current_Usage_Sense REV_B.sch]
2014-12-14 Added Assembly Plan for REV_B board
2014-12-23 Changed assembly plan
2015-01-19 Added new sources and project file
    Support for REV_B board
    Sensor with BMP180 altitude display, setup via button, self calibration
    [Calculation ACS578 Measurement_REV_B.xlsx, SPEKTRUM_Current_Usage_Sense REV_B.brd]
2015-02-22 Added support for the Flight pack capacity sensor
    and some i2c protocols
    [spektel_bmp180_i2c_protocol.csv, spektel_xbus_i2c_protocol.csv]
